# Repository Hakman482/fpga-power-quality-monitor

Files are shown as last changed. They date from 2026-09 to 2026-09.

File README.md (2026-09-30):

# FPGA-Based Single-Phase Power Quality Monitor

A complete hardware–FPGA–software prototype for real-time single-phase power-quality measurement, developed as an MSc Electronic & Electrical Engineering project.

The system combines a custom 4-layer sensing/conditioning PCB, dual 16-bit SAR ADC acquisition, a Nexys A7-100T FPGA processing pipeline, UART telemetry, and a Python desktop GUI. The implementation measures and visualises RMS voltage/current, frequency, active/apparent power, power factor, harmonic distortion, raw ADC samples, waveforms, and voltage-event conditions.

> **Safety:** the hardware includes circuitry intended to interface with hazardous AC voltages. The prototype is an academic/laboratory design, not a certified measurement instrument. Do not connect it to mains unless you are qualified to work on hazardous voltages and have independently verified isolation, protection, creepage/clearance, grounding, enclosure and test procedures.

## Project highlights

- Custom **4-layer PCB** for isolated voltage sensing and Hall-effect current sensing.
- Two synchronized **ADS8320 16-bit SAR ADC** channels.
- **Nexys A7-100T / Artix-7** FPGA (`xc7a100tcsg324-1`).
- **10 kS/s per channel** synchronized acquisition.
- FPGA implementations for cycle-synchronous RMS, frequency measurement, active/apparent power, power factor, adaptive harmonic analysis through the 25th harmonic, and THD calculation.
- Real-data mode selected in the supplied top-level design (`TEST_MODE => false`).
- **115200-baud UART** with separate metric and waveform/raw-ADC packet formats.
- Python/Tkinter GUI with live dashboard, waveforms, raw ADC view, spectrum, events, validation tools and CSV recording.
- Experimental validation using function-generator voltage tests and DC current calibration, with measurement-uncertainty analysis.

## System architecture

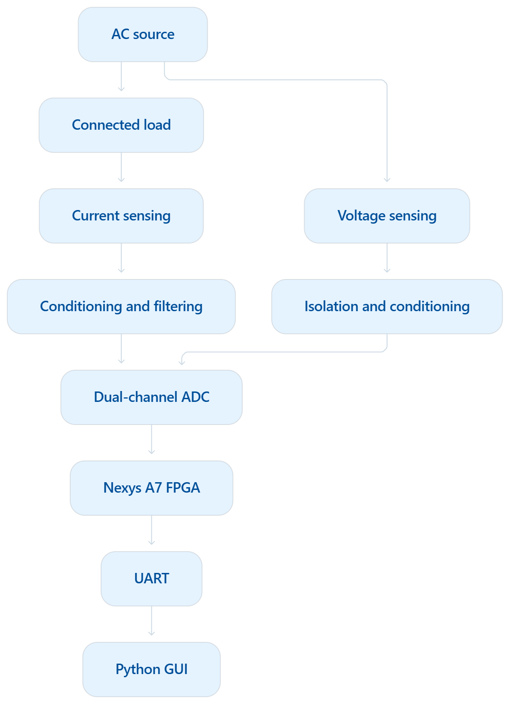
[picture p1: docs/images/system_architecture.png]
System architecture


`Voltage / Current sensing -> analogue conditioning -> dual ADC -> FPGA acquisition/DSP -> UART -> Python GUI`

### Measurement hardware

The voltage path uses an isolated-amplifier-based sensing chain followed by precision op-amp conditioning and anti-alias filtering before conversion by an ADS8320.

Current is sensed using an ACS724 Hall-effect sensor, conditioned around the analogue midpoint, filtered and digitised by the second ADS8320.

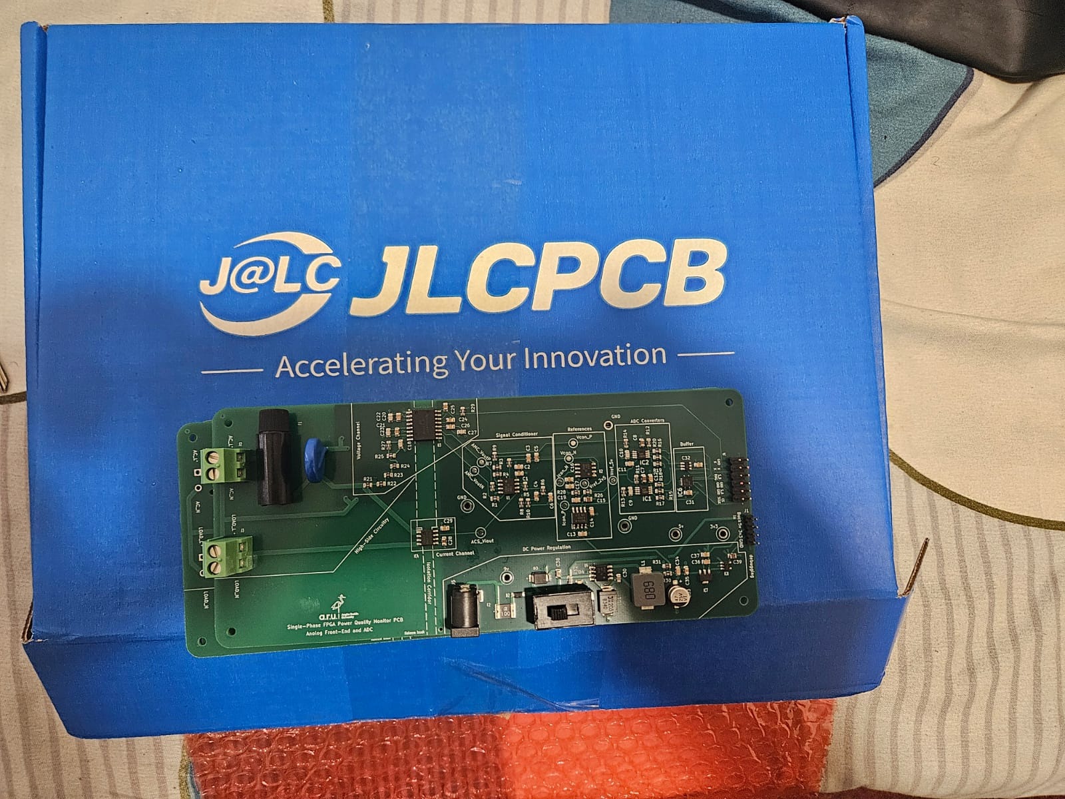
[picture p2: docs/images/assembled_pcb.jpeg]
Assembled PCB


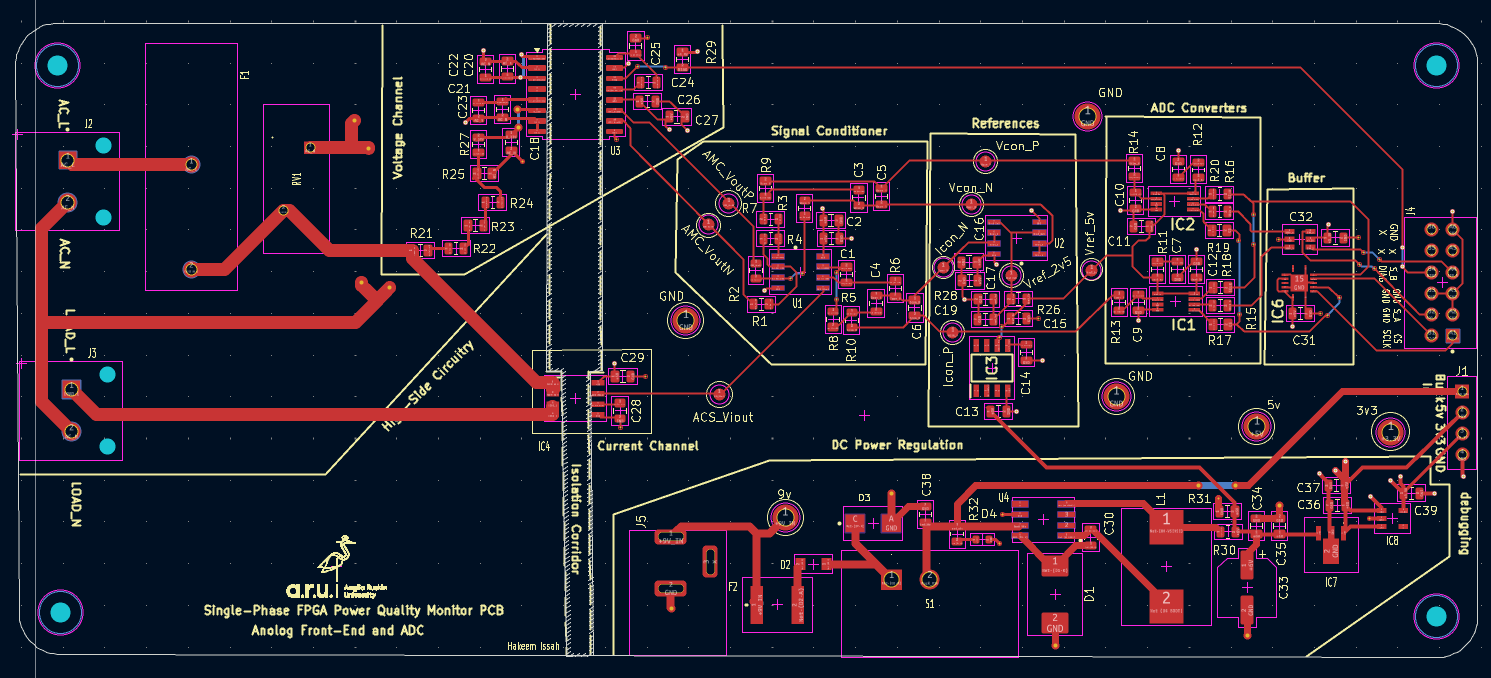
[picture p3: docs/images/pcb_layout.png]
PCB layout


## FPGA architecture

The final hardware design is in [`fpga/`](fpga/).

| Parameter | Value |
|---|---:|
| FPGA | Nexys A7-100T / `xc7a100tcsg324-1` |
| System clock | 100 MHz |
| ADC serial clock | 500 kHz |
| Sampling rate | 10 kS/s/channel |
| Nominal mains frequency | 50 Hz |
| Nominal RMS/power window | 200 samples |
| Maximum adaptive THD cycle frame | 210 samples |
| UART | 115200 baud, 8N1 |
| Waveform frame | 1000 sample pairs |
| Waveform capture interval | approximately 2 s |

See [`fpga/README.md`](fpga/README.md) for the module breakdown and Vivado build instructions.

## UART protocol and GUI

Two packet families are transmitted:

- `AA55`: FPGA-computed power-quality metrics.
- `AA56`: versioned V/I sample frames containing raw 16-bit ADC codes and scaled engineering-unit samples.

A 1000-pair frame represents 100 ms of data at 10 kS/s, or about five cycles of a 50 Hz waveform. Continuous raw streaming is deliberately avoided because 115200-baud UART cannot carry the full 10 kS/s sample stream continuously.

The Python GUI is in [`gui/`](gui/).

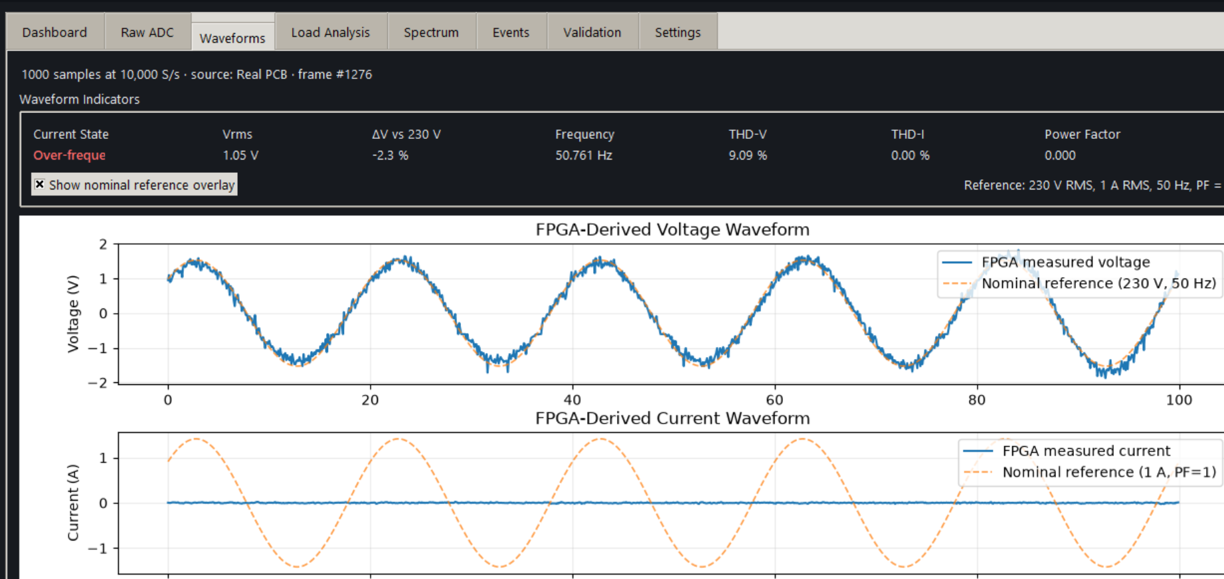
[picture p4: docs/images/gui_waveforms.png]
GUI waveform view


```bash
cd gui
python -m pip install -r requirements.txt
python main.py
```

## Validation

The project was validated using low-voltage sinusoidal input tests for the voltage chain and DC current calibration for the current chain. Oscilloscope/logic measurements were also used to verify conversion cadence, ADC serial-clock bursts and activity on both ADC data lines.

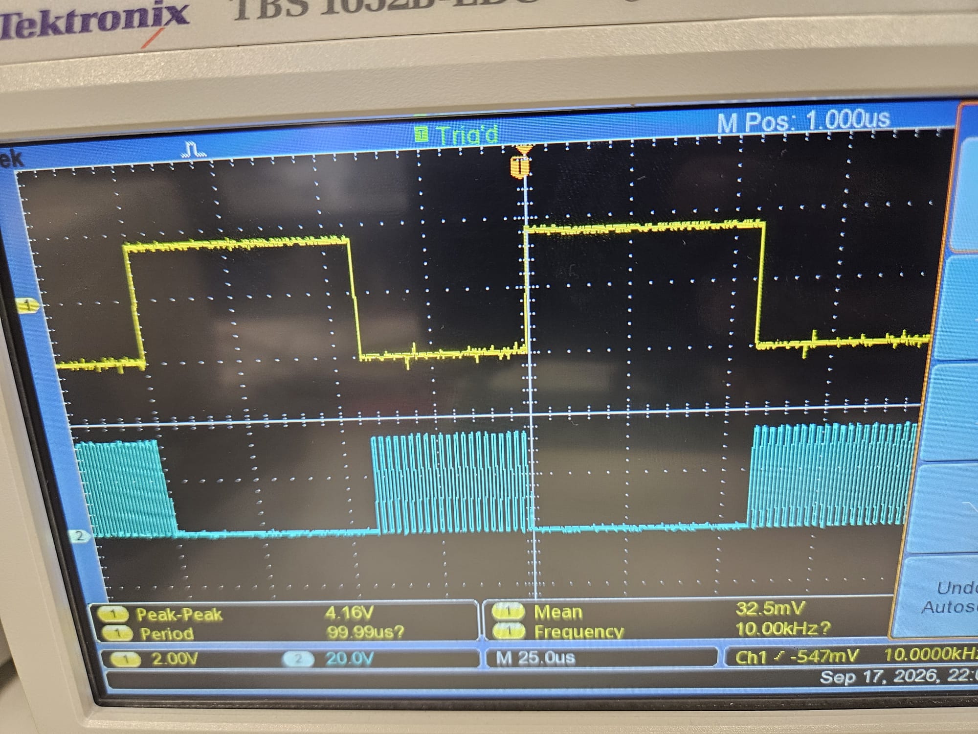
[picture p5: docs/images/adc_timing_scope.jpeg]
ADC timing verification


The original GUI CSV format is preserved. Most captures are stored directly as `.csv`. Four captures exceeded the transfer size used to populate this repository and are therefore stored **losslessly** as gzip-compressed CSV files:

- `validation/current/raw/raw_adc_0.05A.csv.gz`
- `validation/current/raw/raw_adc_0.2A.csv.gz`
- `validation/current/raw/raw_adc_0.25A.csv.gz`
- `validation/voltage/raw/raw_adc_cali_10pp.csv.gz`

They decompress to the original CSV bytes, e.g.:

```bash
gzip -dk validation/current/raw/raw_adc_0.25A.csv.gz
```

Known isolated acquisition glitches are preserved in the source captures. Analysis excludes isolated invalid codes such as exact `24576` and `49152` samples where they represent acquisition artefacts rather than real measurements. See [`validation/README.md`](validation/README.md).

## Hardware and manufacturing

Editable KiCad sources, the full custom footprint/symbol libraries, repository-relative 3D models, Gerbers, drill files, BOM and component-placement outputs are under [`hardware/`](hardware/).

The board source can be opened from:

```text
hardware/kicad/myProject.kicad_pro
```

## Repository layout

```text
.
├── README.md
├── .gitignore
├── CITATION.cff
├── fpga/
│   ├── src/             # final active VHDL
│   ├── sim/             # simulation/testbench sources
│   ├── legacy/          # earlier auto-disabled modules
│   ├── constraints/
│   └── scripts/
├── gui/                 # Python GUI and UART parser
├── hardware/
│   ├── kicad/
│   └── manufacturing/
├── validation/
│   ├── current/
│   ├── voltage/
│   └── analysis/
└── docs/
    ├── images/
    └── academic/
```

## Rebuilding the FPGA project

Generated Vivado cache/run files are intentionally omitted.

From Vivado Tcl:

```tcl
source fpga/scripts/create_project.tcl
```

The original project was developed with Vivado 2026.1. Re-run synthesis, implementation and timing checks in your installed Vivado release before programming hardware.

## Academic material

The project-defence presentation is included under `docs/academic/`.

The final dissertation itself is not duplicated in this Git repository; the repository is intended to expose the engineering implementation, design files, evidence and reproducible validation assets rather than act as a dissertation archive.

## Scope and limitations

This repository documents a working academic prototype rather than a certified power-quality analyser. Laboratory-source constraints limited voltage validation to low-voltage controlled inputs, and current calibration was performed at sub-ampere DC levels. Transient/event functionality was not developed into a full standards-compliant disturbance classifier.

## Author

**Hakeem Issah**  
MSc Electronic & Electrical Engineering project, 2026.

## Use and licensing

No open-source licence is asserted. The material is shared as academic/portfolio work. Contact the author before reusing substantial portions in another project or publication.

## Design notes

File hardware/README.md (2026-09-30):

# Hardware and PCB

Editable KiCad design files and manufacturing outputs for the custom measurement PCB.

## Design source

Open:

```text
kicad/myProject.kicad_pro
```

The project includes:

- top-level schematic and hierarchical sheets,
- 4-layer PCB layout,
- custom symbols,
- custom footprints,
- 3D component models.

The board implements the voltage/current sensing and conditioning chains, ADC interfaces, reference/power circuitry and FPGA interconnect used by the prototype.

## Manufacturing outputs

`manufacturing/` contains:

- Gerber files,
- plated/non-plated drill files,
- component-placement files,
- BOM,
- JLC assembly placement/CPL export.

These are retained separately from the editable KiCad design so it is clear which files are source and which are generated fabrication outputs.

## Safety and fabrication warning

This board was built and tested as an academic prototype. Manufacturing files are provided for project traceability, not as a statement that the design is certified or suitable for direct deployment on a mains installation.

Before reproducing or energising the board, independently review at least:

- insulation/isolation ratings,
- creepage and clearance,
- fuse/protection coordination,
- earthing and oscilloscope-grounding strategy,
- component voltage/current ratings,
- PCB material and manufacturing tolerances,
- enclosure and touch protection.

Do not infer regulatory compliance from the presence of Gerbers or a successful prototype build.

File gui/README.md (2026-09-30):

# Python GUI

Desktop interface for the FPGA power-quality monitor.

## Features

- FPGA metrics dashboard
- raw 16-bit voltage/current ADC display
- waveform plotting
- spectrum/harmonic view
- event/status table
- validation page
- serial-port settings
- raw CSV recording

No Python-generated measurement source is used in the final application. The selectable data modes refer to whether the FPGA itself is running its internal test source or the physical PCB input path.

## Requirements

```bash
python -m pip install -r requirements.txt
```

Dependencies:

- NumPy
- Matplotlib
- PySerial
- Tkinter (normally provided with desktop Python installations)

## Run

```bash
python main.py
```

Connect to the Nexys A7 USB-UART interface at **115200 baud**.

## Packet formats

### `AA55` metric packet

Carries the FPGA-computed measurement metrics.

### `AA56` waveform/raw packet, protocol version 2

Header and metadata are followed by V/I sample pairs.

Each sample pair contains:

- unsigned 16-bit voltage ADC code,
- unsigned 16-bit current ADC code,
- signed 32-bit voltage in millivolts,
- signed 32-bit current in microamps.

Multi-byte fields are MSB-first.

The final FPGA configuration captures 1000 sample pairs at 10 kS/s. This preserves the full 100 µs sample spacing within the 100 ms capture without attempting to stream every sample continuously over the 115200-baud serial link.

## CSV capture

Raw recording keeps both original ADC codes and scaled values. The data in `../validation/` was captured through this path.

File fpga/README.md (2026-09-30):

# FPGA implementation

This directory contains the final VHDL implementation for the Nexys A7-100T and the associated simulation sources.

## Active synthesis sources

| Module | Purpose |
|---|---|
| `pq_nexys_top.vhd` | Final top-level integration: acquisition, DSP, packet formatting and UART. |
| `acquisition_pipeline.vhd` | Selects internal-test or real-ADC acquisition and coordinates the measurement pipeline. |
| `adc_if.vhd` | ADS8320 serial-interface building block. |
| `dual_adc_if.vhd` | Simultaneously controls the two ADS8320 channels and returns synchronized 16-bit samples. |
| `sample_preprocess.vhd` | Removes measured channel zero offsets and produces signed, zero-centred ADC counts. |
| `sample_scale_v2.vhd` | Converts zero-centred counts to voltage/current engineering units using measured calibration factors. |
| `dual_rms.vhd` | Cycle-synchronous voltage/current RMS engine. |
| `frequency_meter.vhd` | Frequency measurement from the conditioned voltage waveform. |
| `power_meter_v2.vhd` | Cycle-synchronous active/apparent power and power-factor calculation. |
| `sample_frame_buffer.vhd` | Stores one adaptive electrical cycle for harmonic processing. |
| `harmonic_1_25_extractor.vhd` | Fixed-point Goertzel harmonic engine for the fundamental and harmonics 2–25. |
| `thd_1_25_meter.vhd` | Converts harmonic energy terms into V/I THD results. |
| `test_signal_source.vhd` | Internal deterministic waveform source for FPGA-only validation. |
| `pq_uart_packet_tx.vhd` | Formats metric packets plus raw/scaled V/I sample frames. |
| `uart_tx.vhd` | 115200-baud byte transmitter. |

Earlier modules that were auto-disabled in the submitted Vivado project are retained in `legacy/` for traceability but are not added by the clean build script.

## Final configuration

The supplied `pq_nexys_top.vhd` uses:

```vhdl
TEST_MODE => false
```

so normal synthesis targets the physical PCB/ADS8320 acquisition path.

Important values in the final top level:

```text
SYS_CLK_HZ            = 100,000,000
ADC_DCLOCK_HZ         = 500,000
SAMPLE_RATE_HZ        = 10,000
RMS_WINDOW_SAMPLES    = 200
POWER_WINDOW_SAMPLES  = 200
THD_FRAME_SAMPLES     = 210
SAMPLE_FRAME_SAMPLES  = 1,000
FRAME_PERIOD_SAMPLES  = 20,000
UART_BAUD              = 115,200
```

## Pin mapping

The included XDC targets the Nexys A7-100T:

| Function | Board pin |
|---|---|
| 100 MHz clock | E3 |
| Reset / BTNC | N17 |
| ADC chip select / JA1 | C17 |
| ADC serial clock / JA2 | D18 |
| Voltage ADC data / JA3 | E18 |
| Current ADC data / JA4 | G17 |
| USB-UART TX | D4 |

## Clean Vivado project

Generated Vivado output is deliberately not stored in the repository.

Run the project-generation Tcl script from the repository root:

```tcl
source fpga/scripts/create_project.tcl
```

Then run Synthesis, Implementation and Generate Bitstream.

Target device:

```text
xc7a100tcsg324-1
```

The original project file was created with Vivado 2026.1.

## Simulation

The `sim/` directory contains focused testbenches for the acquisition interface, RMS, frequency, harmonic/THD pipeline, power meter, UART packets and the integrated PQ pipeline.

Some testbenches exercise legacy variants as part of the development record; use the final `*_1_25_*`, `power_meter_v2` and `pq_uart_packet_tx` paths for the final architecture.

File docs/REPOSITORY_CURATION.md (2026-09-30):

# Repository curation notes

The original working archive contained 884 items, including source files, generated build artefacts, backups, research literature, component datasheets, repeated photographs and laboratory captures.

This GitHub package intentionally keeps the engineering outputs that are useful for review and reproduction while excluding unrelated or redundant material.

## Included

- final active VHDL implementation;
- VHDL simulation/testbench sources;
- earlier auto-disabled VHDL modules under `fpga/legacy/`;
- final Nexys A7 constraints;
- Python GUI and UART protocol code;
- editable KiCad schematic/PCB files;
- custom KiCad symbols, footprints and 3D models;
- Gerber/drill/BOM/placement manufacturing outputs;
- raw voltage/current validation CSV files;
- final dissertation and defence presentation;
- selected photographs/screenshots that document the system.

## Excluded

- Vivado cache, synthesis/implementation run folders, checkpoints, logs and generated bitstream;
- KiCad automatic backups;
- duplicate/near-duplicate photographs;
- exploratory screenshots that do not add useful documentation;
- downloaded research papers;
- vendor datasheets;
- temporary notes and miscellaneous debugging artefacts.

Research papers and vendor datasheets are deliberately not republished here because they are third-party material and are not required to understand the implementation.

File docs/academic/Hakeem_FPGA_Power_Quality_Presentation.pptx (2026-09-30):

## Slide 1

ENGINEERING MAJOR PROJECT

FPGA-Based Power Quality
Monitoring

with Measurement Uncertainty Analysis

Hakeem Issah (2452525)

MSc Electronic/Electrical Engineering
Anglia Ruskin University · September 2026
Supervisor: Dr. Sufian Yousef

Custom 4-layer sensing PCB + Nexys A7 FPGA + Python GUI

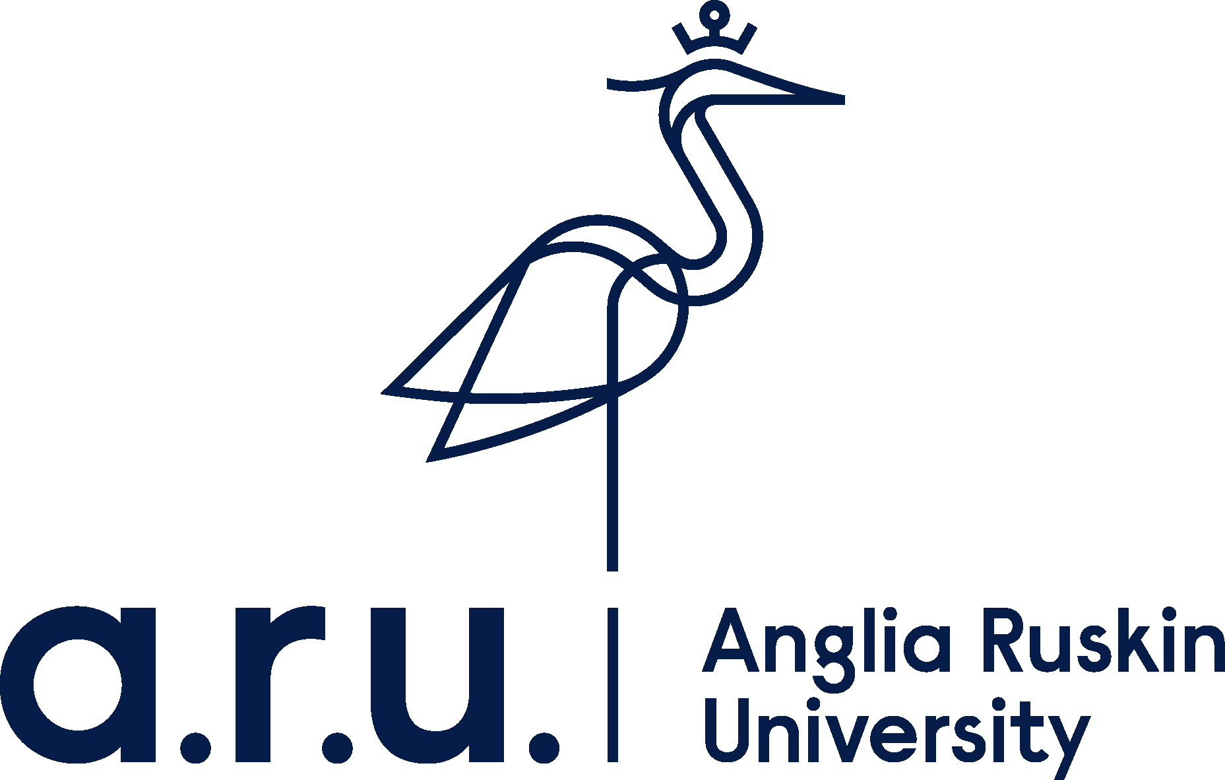
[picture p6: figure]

10-minute presentation

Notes: Good morning. My project is an FPGA-based single-phase power quality monitoring system with a particular focus on measurement uncertainty. The system combines a custom analogue sensing PCB, two 16-bit ADS8320 ADCs, a Nexys A7 FPGA and a Python GUI. Rather than only showing that the algorithms work, I also evaluated how well the complete measurement chain represents the applied input and where the available reference instruments limit the conclusions.

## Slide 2

MOTIVATION

Problem and project aim

The engineering problem

Correct FPGA maths does not guarantee correct measurement.
Sensor offset, analogue gain, noise, ADC reference and channel timing can all alter the samples before processing.

A prototype must therefore be tested as a complete measurement chain.

Sensing

Conditioning

16-bit ADC

FPGA

GUI

measurement uncertainty enters before the digital result

Design and implement a single-phase FPGA-based power quality monitor, then evaluate its measurement-chain performance using calibration, reference comparisons and uncertainty analysis.

Project aim

50 Hz nominal

10 kS/s / ch

Single phase

16-bit ADC

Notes: The central problem is that an FPGA can calculate RMS or THD correctly and the displayed answer can still be inaccurate because the samples may already contain gain error, offset, noise or timing error. That is why my aim was not only to build the monitor, but to evaluate the measurement chain itself. The design targets a 50 hertz single-phase system, samples both channels at 10 kilosamples per second, and uses 16-bit ADCs.

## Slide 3

LITERATURE REVIEW

Selected literature and research gap

Study | Relevant evidence | Limit on transfer
Yildirim et al. (2018) | FPGA-based online power-quality monitoring using continuously acquired voltage and current signals. | Different sensing hardware, network conditions and communication architecture.
De Oro Arenas et al. (2021) | FPGA smart-energy meter with analogue acquisition, power-quantity calculation, Goertzel harmonics and calibration. | Three-phase system with different sensors and ADC arrangement.
Maśnicki et al. (2025) | Review stressing modelling, development and validation of the complete measuring channel for power-quality assessment. | General measuring-channel framework; not the exact AMC3330 / ACS724 / ADS8320 chain.

Research gap addressed: complete measurement-chain validation and uncertainty, not only FPGA algorithm demonstration.

FPGA-Based Power Quality Monitoring Hakeem Issah · MSc Electronic/Electrical Engineering · 3

Adapted from dissertation Table 2.1

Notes: This literature-review slide is a short version of the table in Chapter 2. I would explain that previous work supports FPGA use for deterministic and parallel power-quality processing. Yildirim et al. show online FPGA monitoring, and De Oro Arenas et al. show an FPGA smart-energy meter with Goertzel harmonics and calibration. Maśnicki et al. is important because it stresses that the whole measuring channel must be validated. My gap is therefore not simply implementing another algorithm. It is integrating the sensing PCB, ADCs, FPGA and GUI, then checking what the measurements and uncertainty actually support.

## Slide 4

WHAT I BUILT

System architecture

Separate physical test sources feed a common hardware–FPGA–GUI chain.

Signal generator

voltage test

Voltage sensing

divider + AMC3330

Conditioning

OPA2188 + filter

ADS8320 V

16-bit SAR

Nexys A7

PQ processing

Python GUI

UART 115200

DC supply + load

current test

Current sensing

ACS724 Hall sensor

Conditioning

OPA2188 + filter

ADS8320 I

16-bit SAR

AMC3330

voltage isolation

ACS724

current sensor

2 × ADS8320

conversion

10 kS/s / ch

sampling

Goertzel 1–25

harmonics

Shared ADC control gives a common sampling schedule; exact analogue phase alignment was not physically established.

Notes: This is the overall architecture. The voltage path uses a divider, AMC3330 isolation and OPA2188 conditioning before a dedicated ADS8320. The current path uses an ACS724 Hall sensor, OPA2188 conditioning and a second ADS8320. Both converters are controlled by the Nexys A7 at 10 kilosamples per second. The FPGA calculates the power-quality quantities and sends results to a Python GUI over UART. The two ADCs share control timing, but because the analogue paths are different, that does not by itself prove exact phase alignment.

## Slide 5

PHYSICAL IMPLEMENTATION

Hardware prototype and commissioning

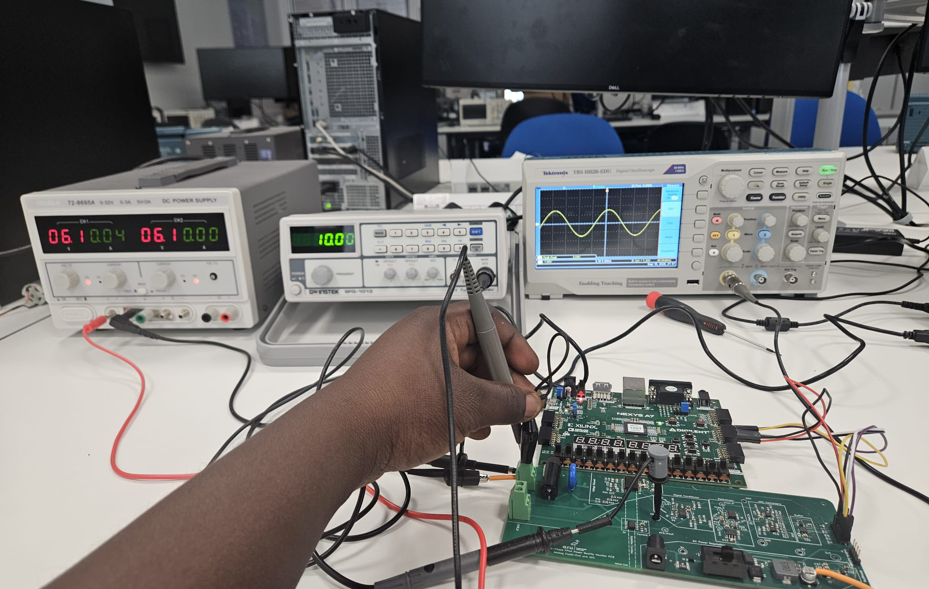
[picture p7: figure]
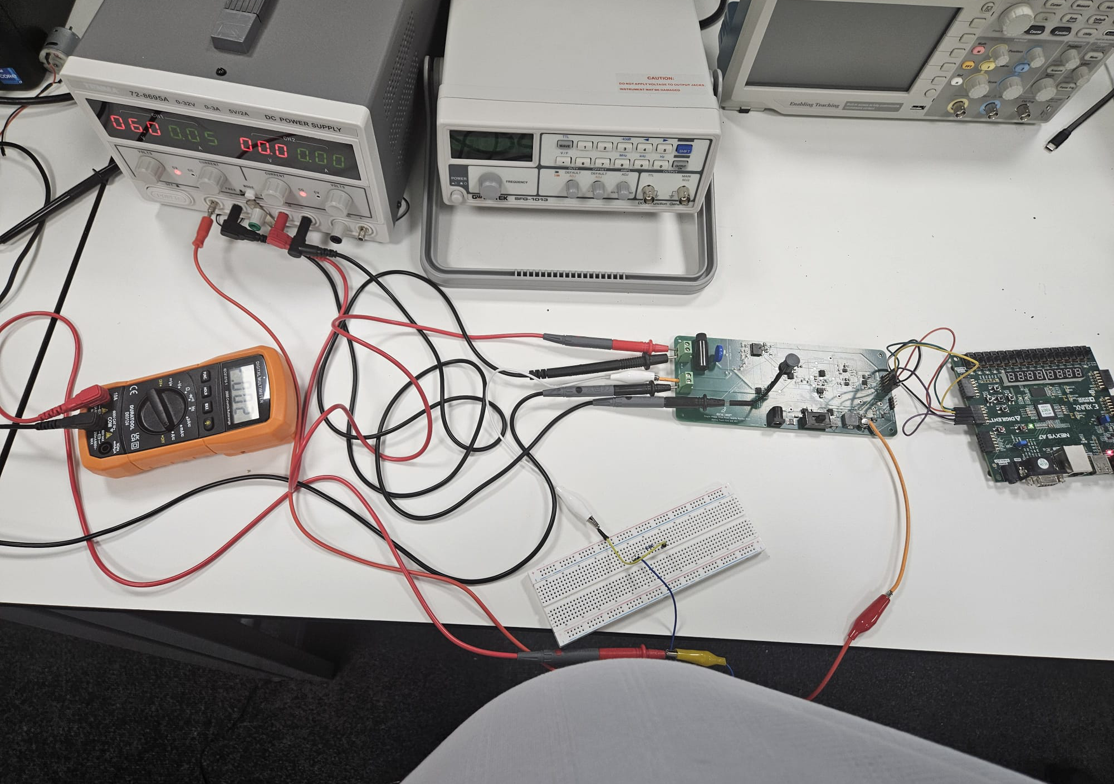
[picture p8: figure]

As-built revisions

• External 6 V applied at C33
• Original 9 V path disconnected
• AMC3330 LDO_OUT–DCDC_IN jumper
• Results refer to this modified configuration

4-layer custom PCB

REF5050 5 V reference

Vcon_P / Vcon_N

Icon_P / Icon_N

Left: voltage-channel lab setup. Top-right: final PCB layout. Bottom-right: DC current test setup.

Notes: The hardware was implemented on a custom four-layer PCB. The board includes isolation and conditioning for voltage, Hall-effect current sensing, a precision five-volt reference and two ADCs. Commissioning also revealed real prototype issues. The original buck-supply section was bypassed, so the final tests used an external six-volt supply at C33, and the AMC3330 required a jumper between LDO_OUT and DCDC_IN. I report those changes explicitly because the results apply to the actual as-tested hardware, not only to the original schematic.

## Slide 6

DIGITAL IMPLEMENTATION

FPGA processing and software interface

ADC pair
16-bit

Offset removal
+ scaling

Parallel
processing

AA55 / AA56
packetisation

UART
115200

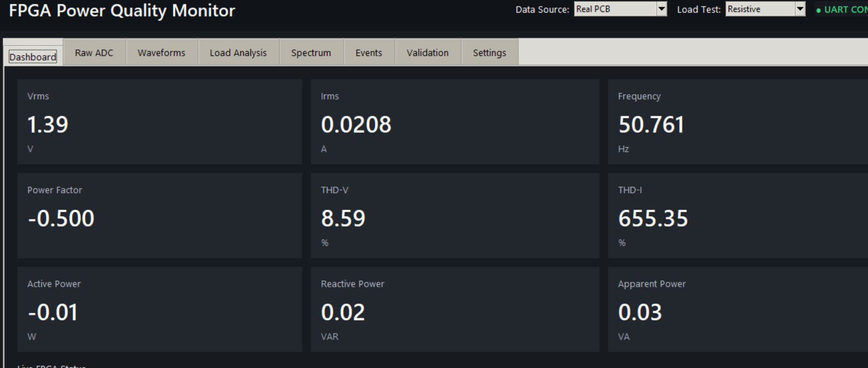
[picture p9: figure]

RMS | frequency | active / apparent power | PF | sag/swell | adaptive Goertzel THD

• TEST_MODE = false for final physical tests
• 1000-sample waveform frames = 0.1 s of data
• Frequency-adaptive Goertzel targets harmonics 1–25
• Fixed-width / integer arithmetic to control FPGA cost
• Raw ADC data can be exported to CSV

Implementation choices

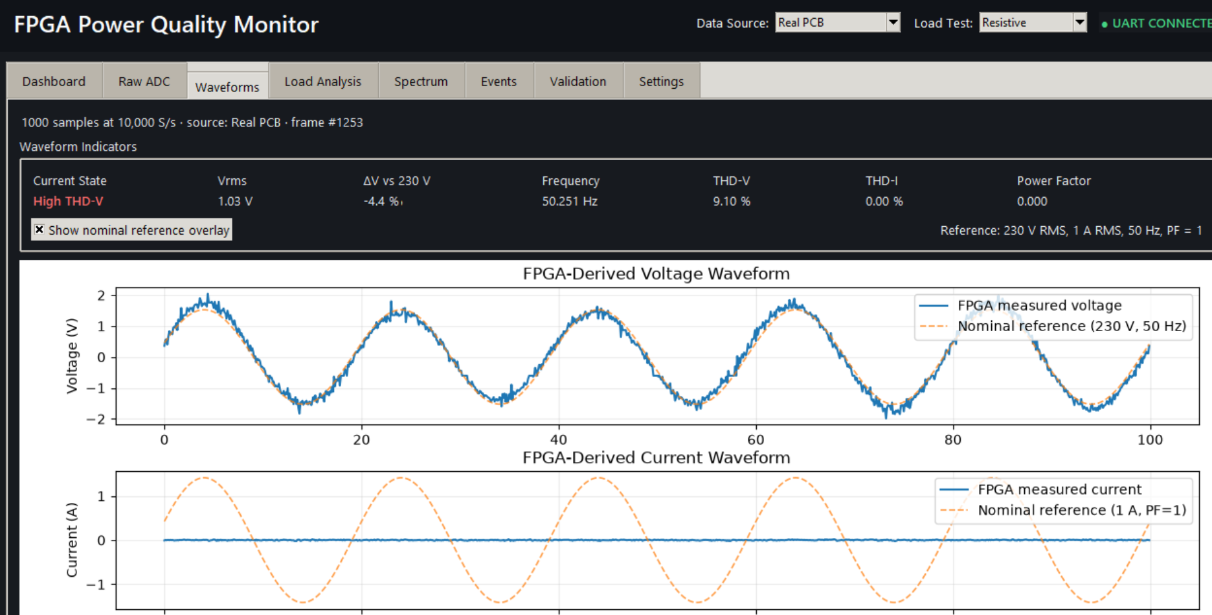
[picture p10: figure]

100 MHz

FPGA clock

100 µs

sample period

1000 samples

frame size

AA56 v2

packet build

115200 baud

host link

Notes: Inside the FPGA, each 16-bit ADC sample is offset-corrected, scaled and fed to several processing blocks in parallel. The implemented functions include RMS, frequency, power, power factor, sag and swell detection, and adaptive Goertzel harmonic processing up to the twenty-fifth harmonic. The final physical tests used TEST_MODE false, so the system processed real ADC samples. Scalar metrics and waveform data are packetised separately and sent to the Python GUI, which also records raw ADC data for offline analysis.

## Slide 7

HOW I TESTED IT

Experimental method

• RMS validation at 3 low-voltage levels
• Frequency operation
• Physical sag/swell detection
• THD behaviour, but no matched independent THD reference

Voltage channel

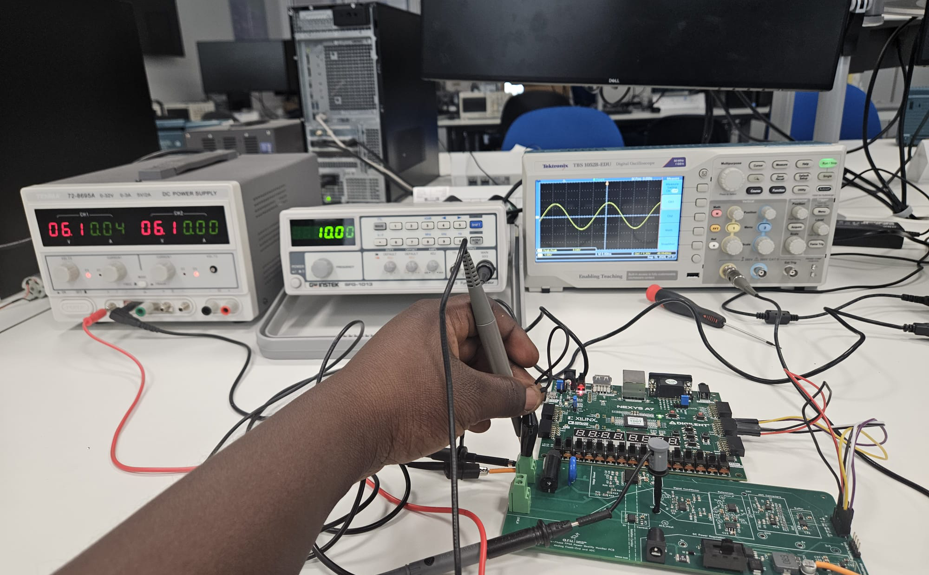
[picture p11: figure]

What it supports

• Zero-input offset and static sensitivity
• DC calibration over 0–0.46 A
• Linearity and repeatability
• Not AC current, phase or harmonic validation

Current channel

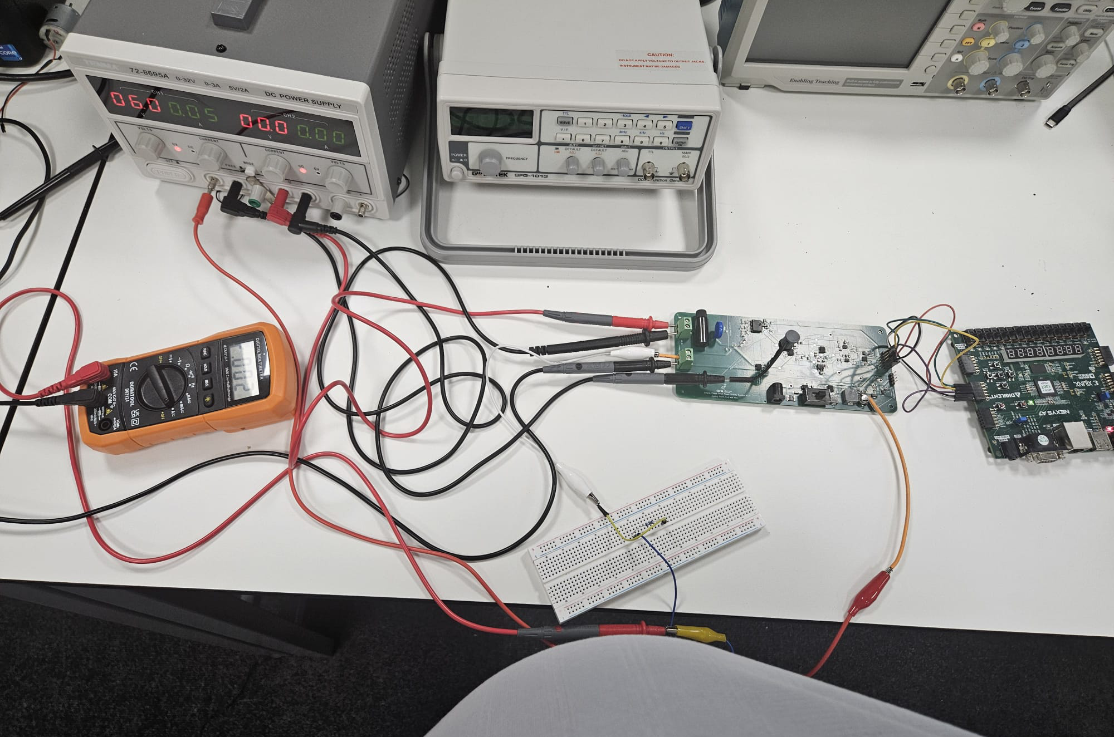
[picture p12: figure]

What it supports

Input / reference

Signal generator + Tektronix TBS1052B-EDU with P2200 probe at 10×

Input / reference

DC bench supply + resistive load + Duratool D03124 multimeter on 10 A range

Important scope decision: the channels were tested separately because no suitable isolated variable AC source was available. These were not simultaneous AC-load measurements.

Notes: Because there was no suitable isolated variable AC source, I deliberately used two separate experiments. For voltage, I used a signal generator and measured the actual test-point amplitude with a Tektronix TBS1052B-EDU and P2200 probe at ten-times attenuation. This supports low-voltage RMS comparisons, frequency operation and physical sag and swell tests. For current, I used a DC supply, resistor and Duratool D03124 on its ten-amp range, covering zero to about 0.46 amps. That supports static calibration and linearity, but not AC phase, current harmonics or live-load power-factor accuracy.

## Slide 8

WHAT THE DATA SHOWED

Key results

Three-point fit: R² = 0.994 · MAPE = 2.63%

Voltage RMS validation

DC current-channel validation

Observed comparison differences were small, but the reference DMM was too coarse for mA-level accuracy claims.

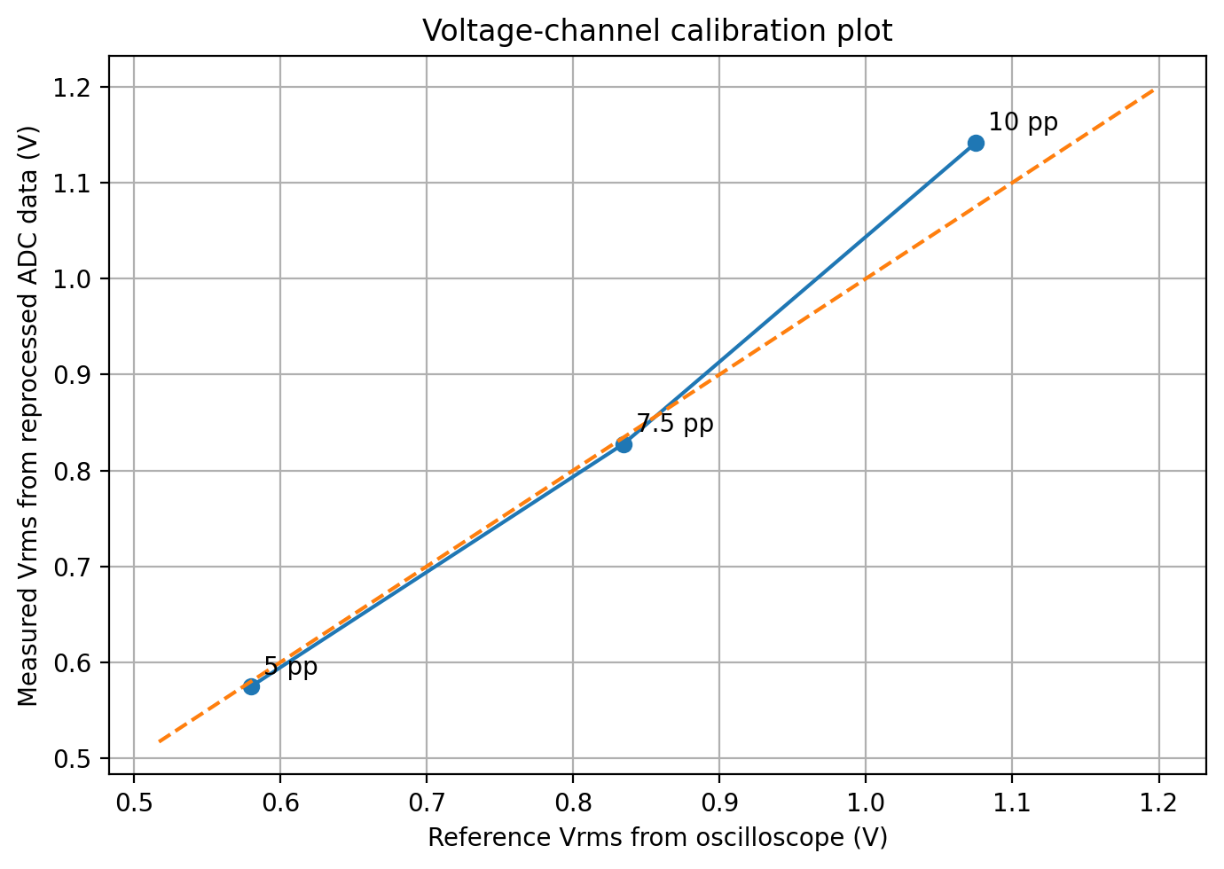
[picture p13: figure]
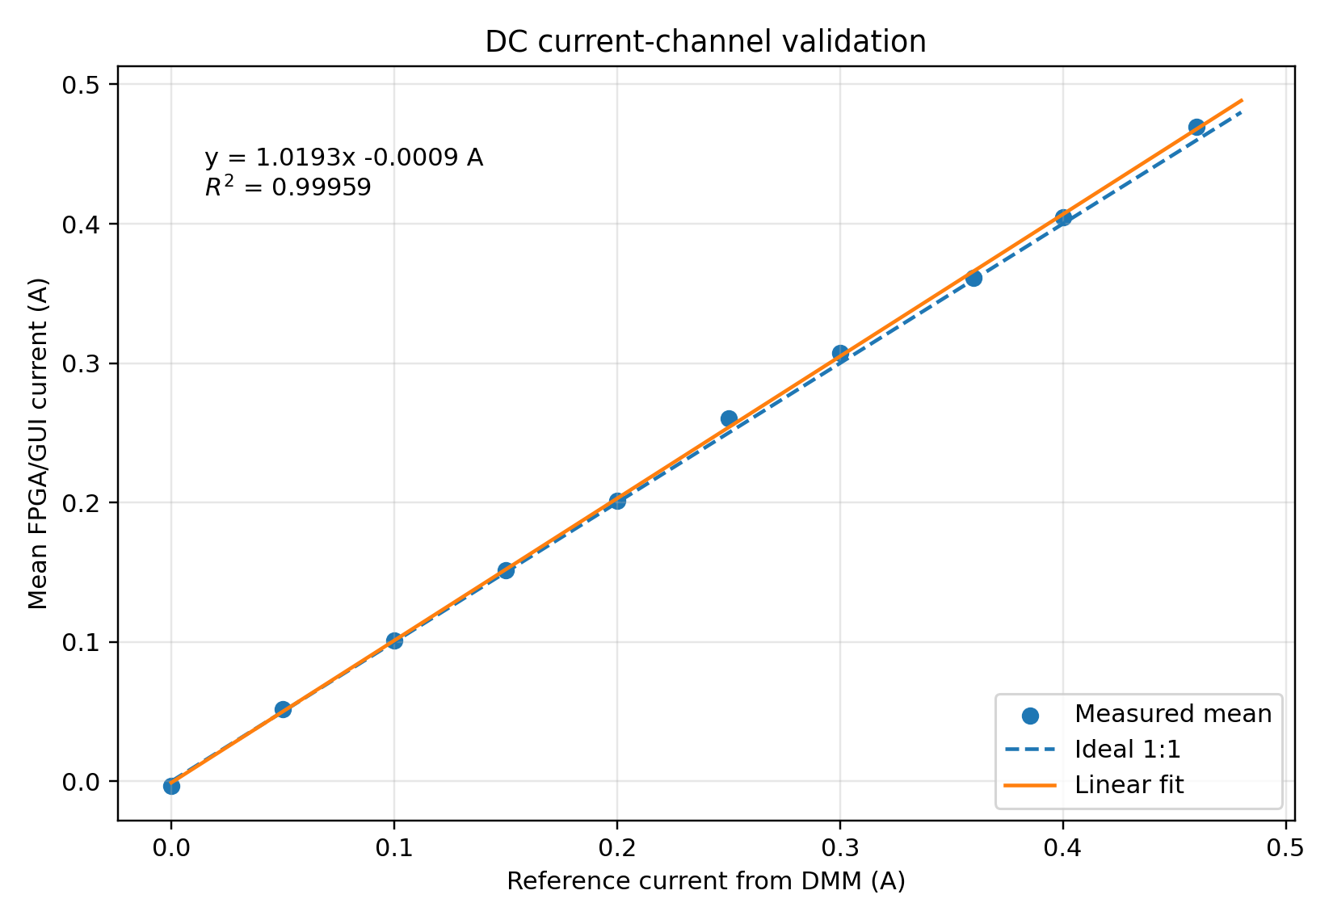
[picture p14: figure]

−0.90%

5 Vpp nominal

−0.81%

7.5 Vpp nominal

+6.18%

10 Vpp nominal

0–0.46 A

tested range

R² 0.99959

linearity

1.0193×

gain fit

CS = 10.00 kHz

physical sample cadence

WNS +0.327 ns

timing closure

LUT 10.43%

resource use

DSP 25.0%

resource use

Sag/swell functional

events

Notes: These are the key quantitative results. For voltage RMS, the first two test levels agreed with the oscilloscope to within about one percent, while the highest level showed a positive error of 6.18 percent. The three-point response was still strongly linear, with an R-squared of 0.994. For the current channel, the response from zero to 0.46 amps was extremely linear, with R-squared approximately 0.9996. On the FPGA side, the measured conversion cadence was 10 kilohertz, the final build met timing with positive worst setup slack, and resource utilisation remained modest. Physical sag and swell changes were also detected successfully.

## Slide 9

WHAT CAN BE CLAIMED

Voltage uncertainty and limitations

Voltage RMS error vs U(k=2)

U(k=2): ±37.2 mV · ±41.5 mV · ±56.7 mV

Voltage RMS uncertainty contributors

Main contributors: scope gain, probe attenuation, repeatability and zero shift.

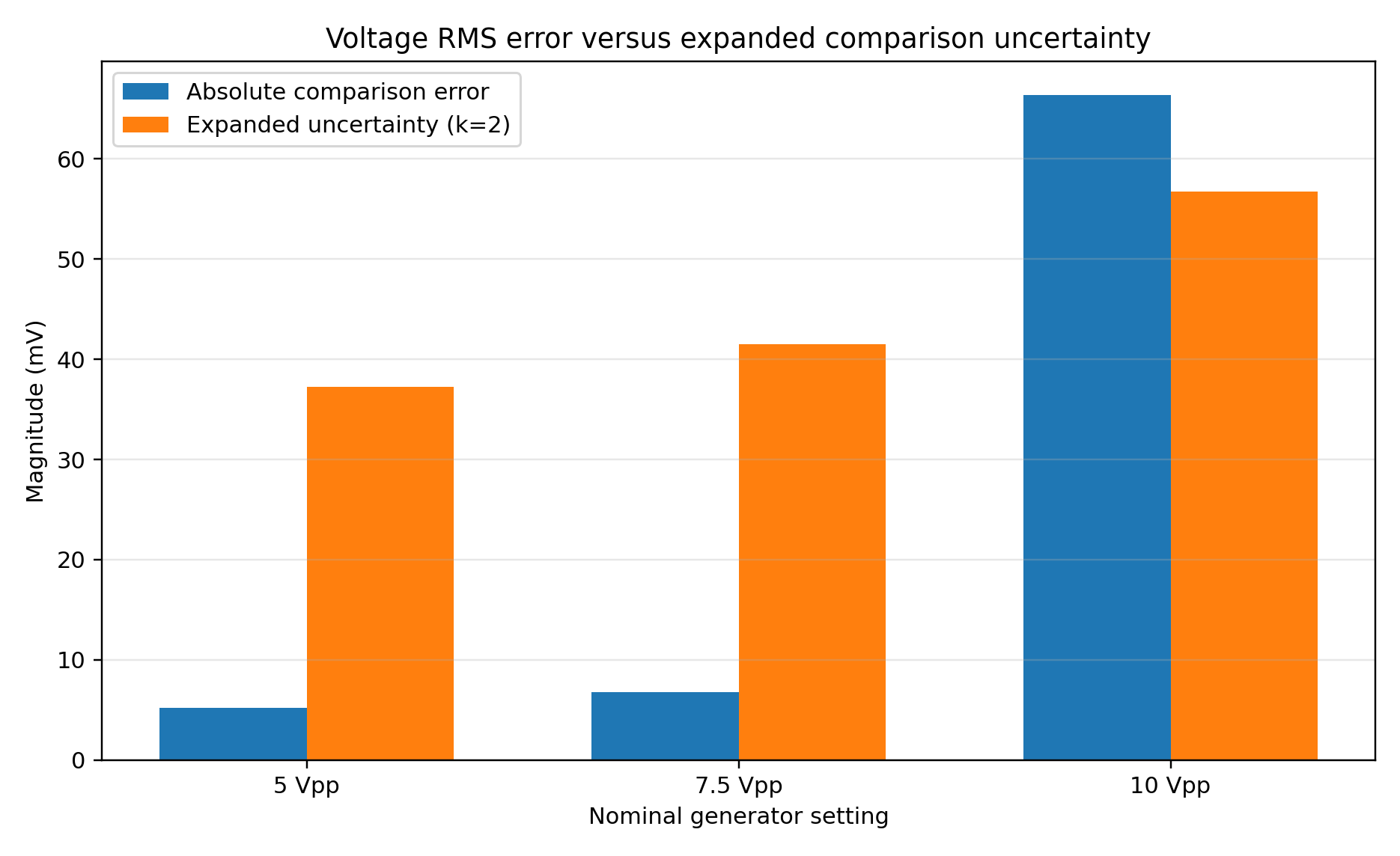
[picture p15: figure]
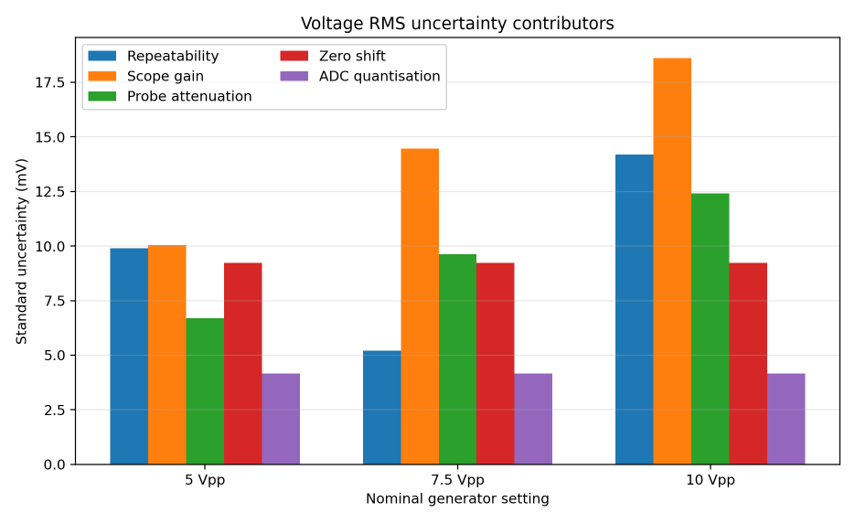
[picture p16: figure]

The 5 Vpp and 7.5 Vpp RMS errors are inside the estimated k=2 comparison intervals.
The 10 Vpp residual is still outside the interval, so an additional systematic effect or missing term is likely.
Therefore, the voltage channel is functional and roughly linear, but not justified as uniformly accurate across the range.

Interpretation

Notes: This slide explains how the results should be interpreted. For voltage, the expanded comparison uncertainties were about plus or minus 37, 42 and 57 millivolts. The first two errors fall inside those intervals, but the 10 Vpp residual of about 66 millivolts remains outside, suggesting an additional systematic effect or a missing uncertainty contribution. For current, the DMM ten-amp range dominates the uncertainty, so the experiment demonstrates linear response but not milliampere-level absolute accuracy. The key point is that the prototype works, but the evidence does not justify unsupported claims about simultaneous AC power, power factor or independently validated THD accuracy.

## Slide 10

WHAT CAN BE CLAIMED

Current uncertainty and limitations

Current uncertainty at 0.30 A

DMM Type-B term ≈ 32.3 mA standard uncertainty

The current channel response is highly linear over 0–0.46 A: R² ≈ 0.9996.
However, the Duratool D03124 was used on its 10 A range, so the reference uncertainty dominates.
Frame repeatability and ADC quantisation are very small compared with the DMM term.
The test supports DC calibration and response shape, but not milliampere-level absolute accuracy.

Need a calibrated low-current reference before high-accuracy claims.

Interpretation

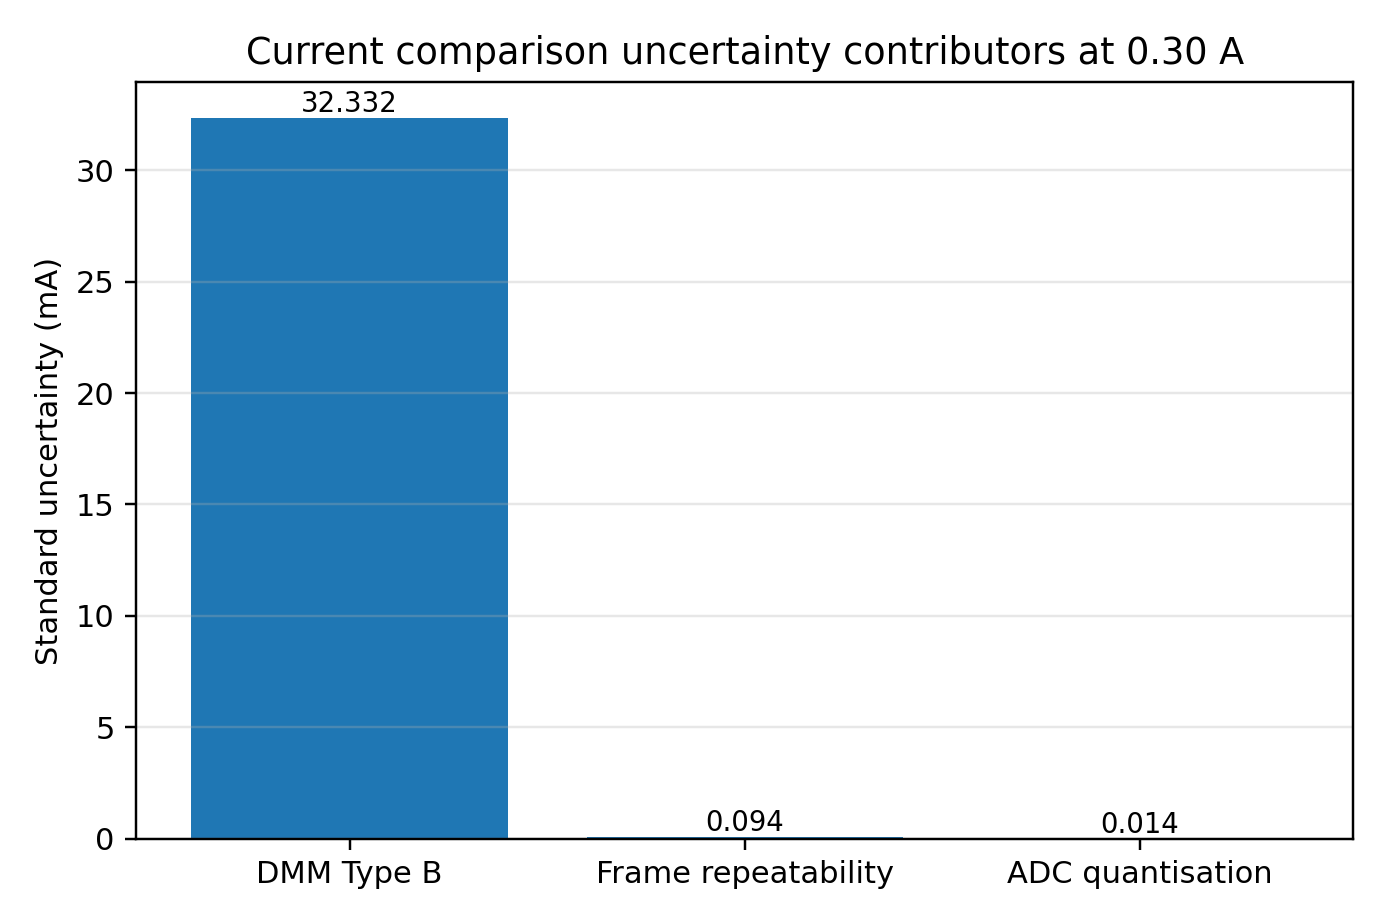
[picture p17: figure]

Main limit

Boundary: DC current calibration was completed; AC current, phase, power and power-factor accuracy were not physically validated.

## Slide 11

Conclusion and future work

Overall: the prototype is a functioning platform; the strongest future step is improved metrology, then full AC validation.

TAKEAWAY

Working FPGA power-quality prototype achieved.

Integrated platform

Custom sensing PCB, two ADS8320 ADCs, Nexys A7 FPGA, UART and Python GUI.

Validated evidence

Voltage RMS at three levels, DC current calibration, physical sag/swell and FPGA timing/resource results.

Key judgement

Functionality was claimed only where real test evidence and uncertainty support it.

Final result

Improve reference instruments

Use calibrated voltage and lower-current references.

Investigate 10 Vpp residual

Repeat with a documented reference chain and additional amplitude points.

Complete AC validation

Use an isolated AC source for phase, power and power-factor testing.

Validate THD independently

Apply known harmonic content and compare with a calibrated reference.

Revise hardware

Correct the power section and integrate the AMC3330 link on PCB.

Next steps

1

2

3

4

5

FPGA-Based Power Quality Monitoring

Hakeem Issah · MSc Electronic/Electrical Engineering

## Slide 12

THANK YOU

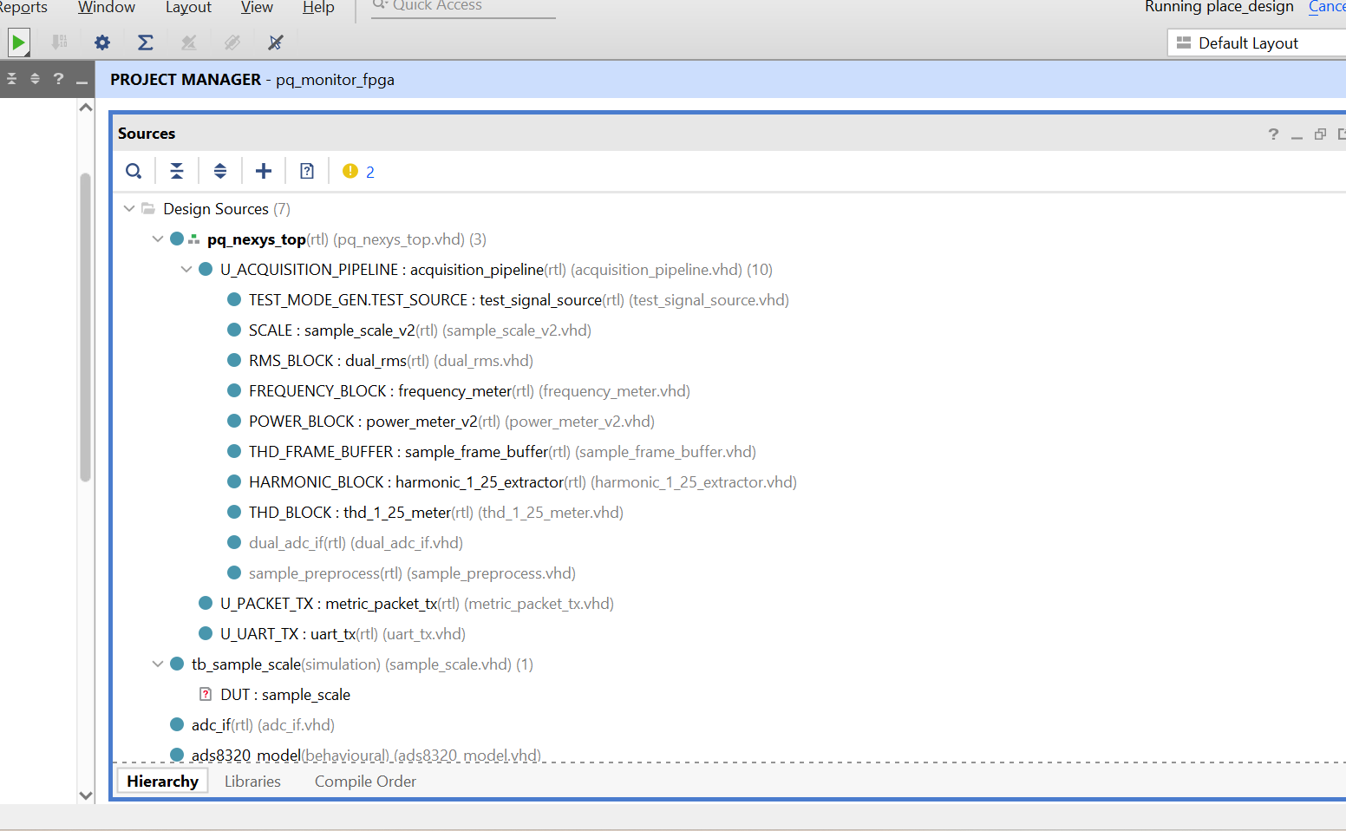
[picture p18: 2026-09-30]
docs/images/vivado_project.png

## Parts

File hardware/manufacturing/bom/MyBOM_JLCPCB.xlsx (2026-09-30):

Comment | Designator | Footprint | JLCPCB Part #（optional）
744770168 | L1 | Inductor_new_YJYCOIN_YSPI1040T_custom | C49140886
XDJK-0051-025_barrel | J5 | DC-470-2.1GP_C194407_barrel_custom | C7498153
ADS8320EB_2K5 | IC1,IC2 | SOP65P490X110-8N_ADC_custom | C22247
SN74LVC2G17DBVR | IC5 | SOT95P280X145-6N_buffer_a_b_custom | C10429
AP7375-33W5-7 | IC8 | SOT95P285X140-5N_ldo3.3v_custom | C2877825
OPA2188AID | U2,U1 | SOIC127P599X175-8Nopamp | C17271
1n | C23,C27,C22,C18,C10,C9 | C_0805_2012Metric | C701302
1730395(load) | J3 | PHOENIX_1730395_ac_load_con | C89120
10k | R1,R30,R28,R26,R4,R3,R2 | R_0805_2012Metric | C84376
TPS5410DR | U4 | SOIC127P599X175-8Nbuck | C28867
AMC3330 | U3 | SOIC-16W_7.5x10.3mm_P1.27mm_custom | C2999368
GND | TP15,GND,GND | TestPoint_Plated_Hole_D2.0mm
Vref_2v5 | Vref_2v5 | TestPoint_Pad_D1.5mm
Vref_5v | Vref_5v | TestPoint_Pad_D1.5mm
Icon_N | Icon_N | TestPoint_Pad_D1.5mm
Icon_P | Icon_P | TestPoint_Pad_D1.5mm
Vcon_N | Vcon_N | TestPoint_Pad_D1.5mm
Vcon_P | Vcon_P | TestPoint_Pad_D1.5mm
ACS_Viout | ACS_Viout | TestPoint_Pad_D1.5mm
AMC_VoutN | AMC_VoutN | TestPoint_Pad_D1.5mm
AMC_VoutP | AMC_VoutP | TestPoint_Pad_D1.5mm
+3.3V | 3v3 | TestPoint_Plated_Hole_D2.0mm
+5V | GND | TestPoint_Plated_Hole_D2.0mm
+9V_IN | 9v | TestPoint_Plated_Hole_D2.0mm
L101011MS02Q | S1 | L101011MS02Q_pswitch | C221823
B72214P2271K101 | RV1 | B72214P2271K101MOVV
2k2 | R32 | R_0805_2012Metric | C114561
2k55 | R31 | R_0805_2012Metric | C2681631
47k | R29 | R_0805_2012Metric | C126351
1k | R27,R10,R9,R8,R7 | R_0805_2012Metric | C95781
4k99 | R25 | R_0805_2012Metric | C114542
499k | R24,R23,R22,R21 | R_0805_2012Metric
47 | R20,R19,R18,R17,R16,R15 | R_0805_2012Metric | C114541
100 | R14,R13 | R_0805_2012Metric | C105577
0.22 | R12,R11 | R_0805_2012Metric | C327215
10K | R6 | R_0805_2012Metric | C84376
30K | R5 | R_0805_2012Metric | C126352
69168-112HLF | J4 | AMPHENOL_69168-112HLF_Odd_Even | C225521
1730395(ac_input) | J2 | PHOENIX_1730395_ac_load_con | C89120
Conn_01x04(debugging) | J1 | PinHeader_1x04_P2.54mm_Vertical | C492403
AP7375-50Y-13 | IC7 | AZ7042RTRG1_ldo5v | C22364247
SN74AHCT125RGYR | IC6 | RGY-_S-PVQFN-N14_cs_clk | C2675532
ACS724LLCTR-05AB-T | IC4 | SOIC127P600X175-8N_acs | C459328
REF5050AIDR | IC3 | SOIC127P600X175-8N_REF | C27804
SMD100F-2018-2 | F2 | SMD030F20182_polyfuse | C70149
4525holder & 0215001 fuse_catridge(installed) | F1 | FUSE_4525holder | C3205505
SGT520-1A T1AL250V 5x20mm Fuse | F1-FUSE | 5x20mm Fuse Cartridge (manual insert) | C41367255
SML-D12FWT86 | D4 | LED_0603_1608Metric | C22371379
SMBJ12A | D3 | DIOM4336X265N_tvs | C151251
SS34FA | D2 | SODFL3618X143Nschottky | C719833
B340 | D1 | D_SMC | C85099
10u | C39,C15,C8,C7 | C_0805_2012Metric | C126584
4.7uF | C38 | C_0805_2012Metric | C86040
100n | C37,C35,C32,C31,C29,C25,C24,C21,C16,C1 | C_0805_2012Metric | C83055
1u | C36,C34,C26,C20,C19,C14,C12,C11 | C_0805_2012Metric | C376925
47u | C33 | CP_Elec_6.3x5.8 | C970677
10n | C30 | C_0805_2012Metric | C342877
4n7 | C28 | C_0805_2012Metric | C415370
4u7 | C13,C2,C17 | C_0805_2012Metric | C86040
33n | C6,C5,C4,C3 | C_0805_2012Metric | C5375930

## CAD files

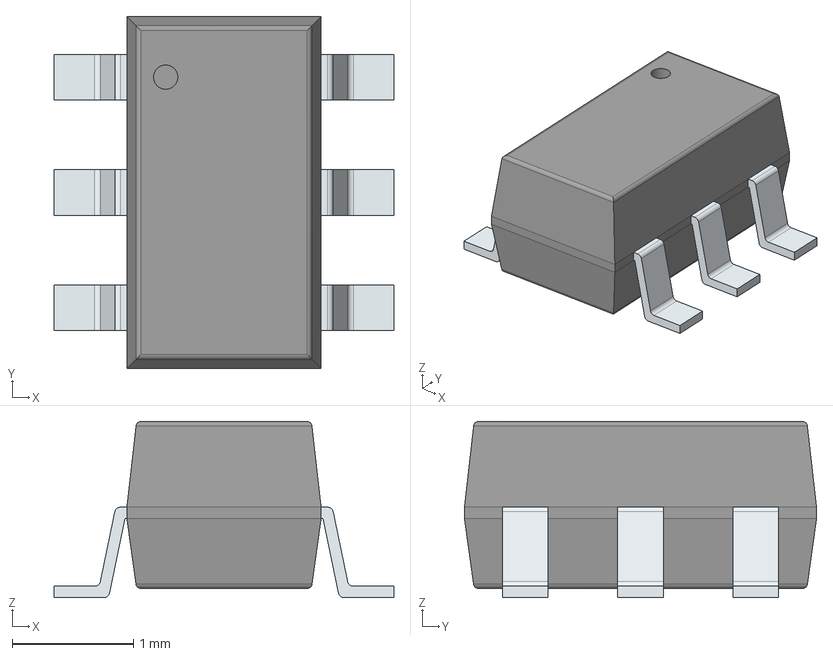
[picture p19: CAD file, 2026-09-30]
hardware/kicad/myProject_models/SN74LVC2G17DBV_buffer_a_b.step
2.80 x 2.90 x 1.45 mm
PinsArrayLR

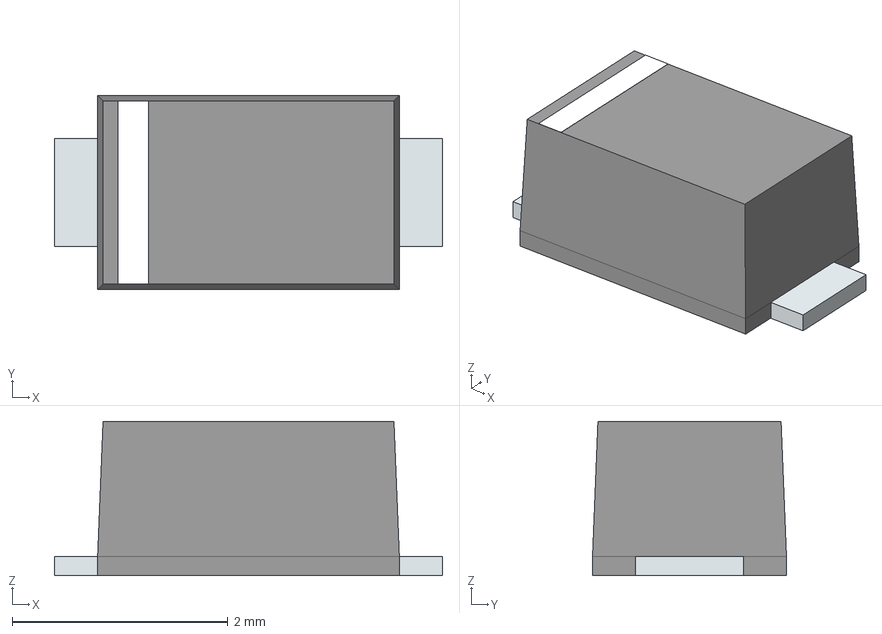
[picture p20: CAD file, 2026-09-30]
hardware/kicad/myProject_models/SS34FAschottky.step
3.60 x 1.80 x 1.43 mm
PinKIdent
PinK
PinA

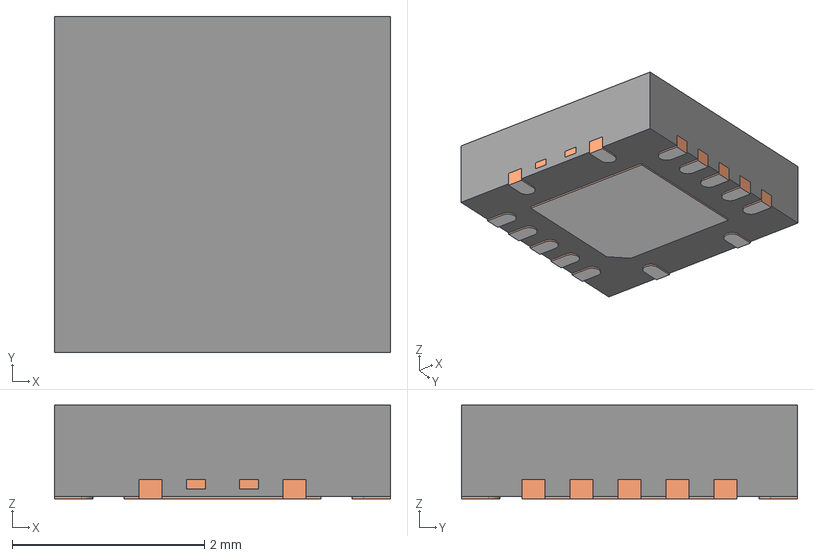
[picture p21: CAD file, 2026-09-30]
hardware/kicad/myProject_models/SN74AHCT125RGYR_buffer_cs_clk.step
3.50 x 3.50 x 0.975 mm
BODY-QFN
FRAME-RWA0014A
PIN1-ID

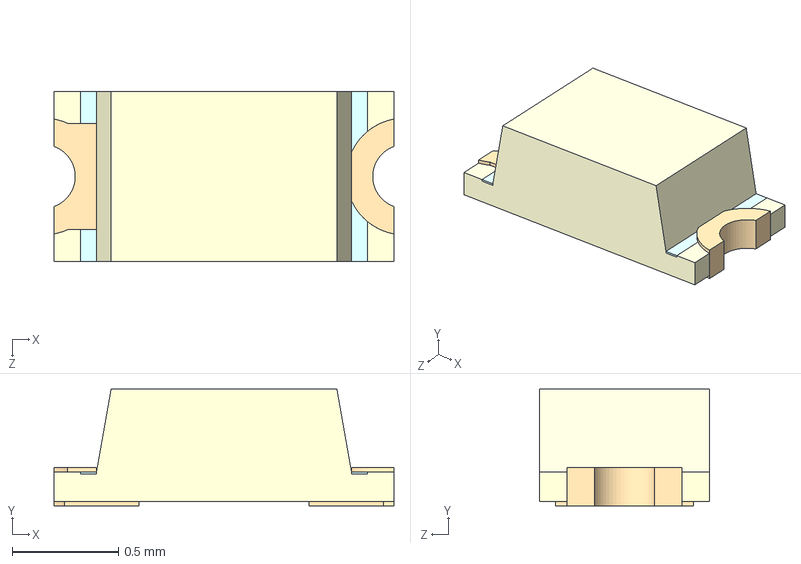
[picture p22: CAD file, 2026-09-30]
hardware/kicad/myProject_models/SML-D12FWT86_gled.step
1.60 x 0.55 x 0.8 mm

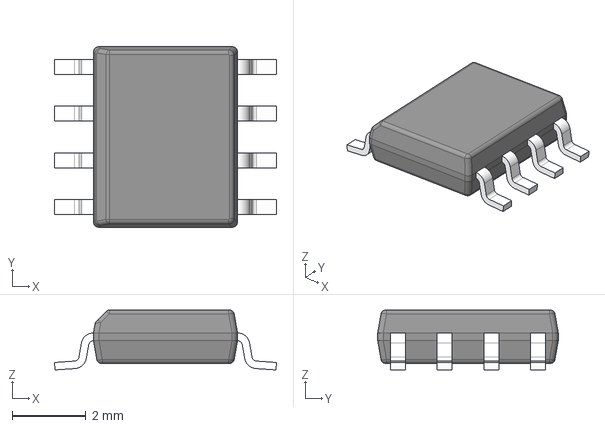
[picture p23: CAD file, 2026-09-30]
hardware/kicad/myProject_models/REF5050AIDR.step
6.02 x 4.90 x 1.63 mm
BODY-SO
LEAD-D0008A x 8

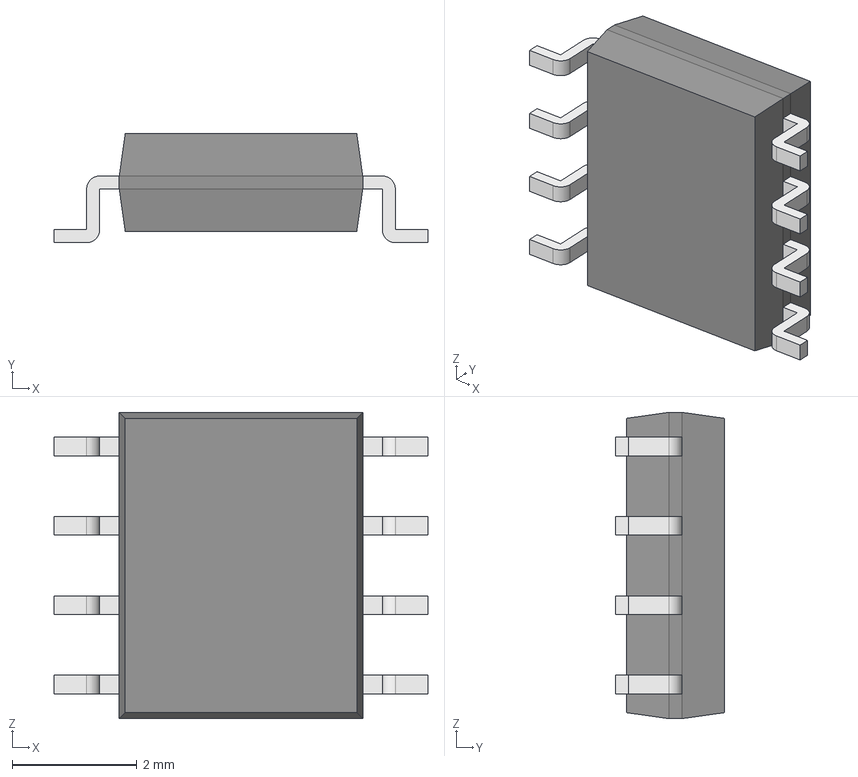
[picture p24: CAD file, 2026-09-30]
hardware/kicad/myProject_models/TPS5410DRbuck.STEP
5.99 x 1.75 x 4.91 mm
Body001 (Mirror #1) x 4
XY-plane x 12
X-axis x 12

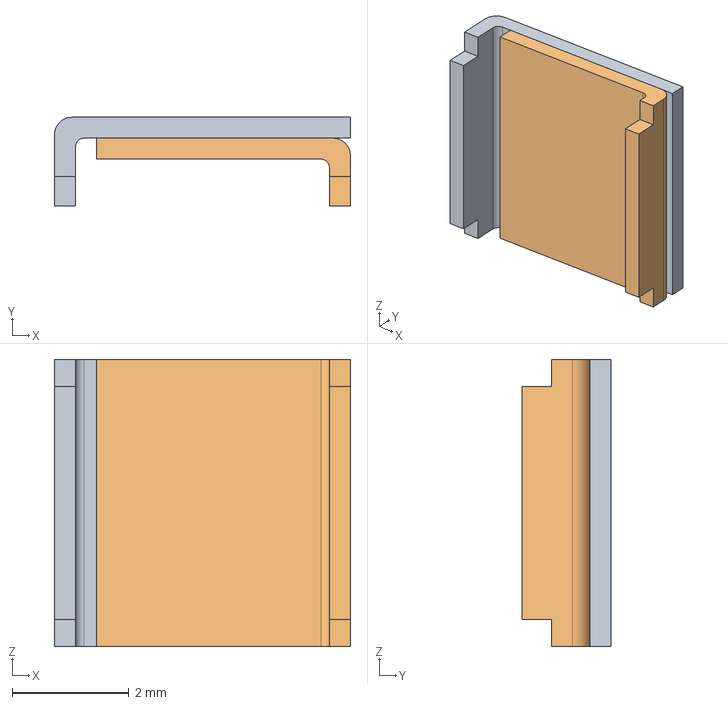
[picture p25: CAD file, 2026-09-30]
hardware/kicad/myProject_models/SMD100F-2018-2_polyfuse.step
5.08 x 1.52 x 4.93 mm

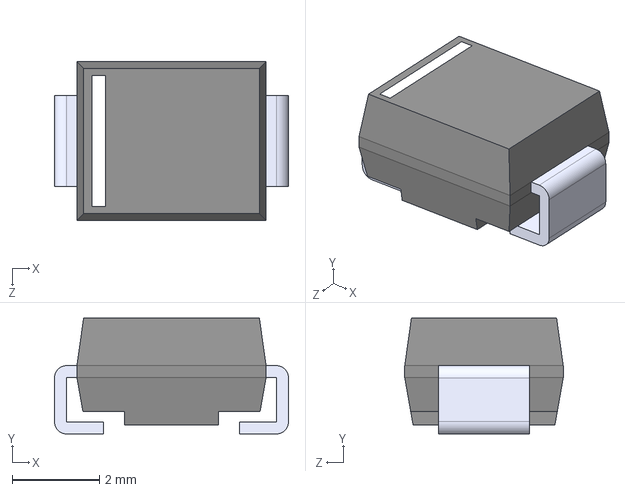
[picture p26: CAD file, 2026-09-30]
hardware/kicad/myProject_models/SMBJ12A_tvs.step
5.35 x 2.65 x 3.62 mm

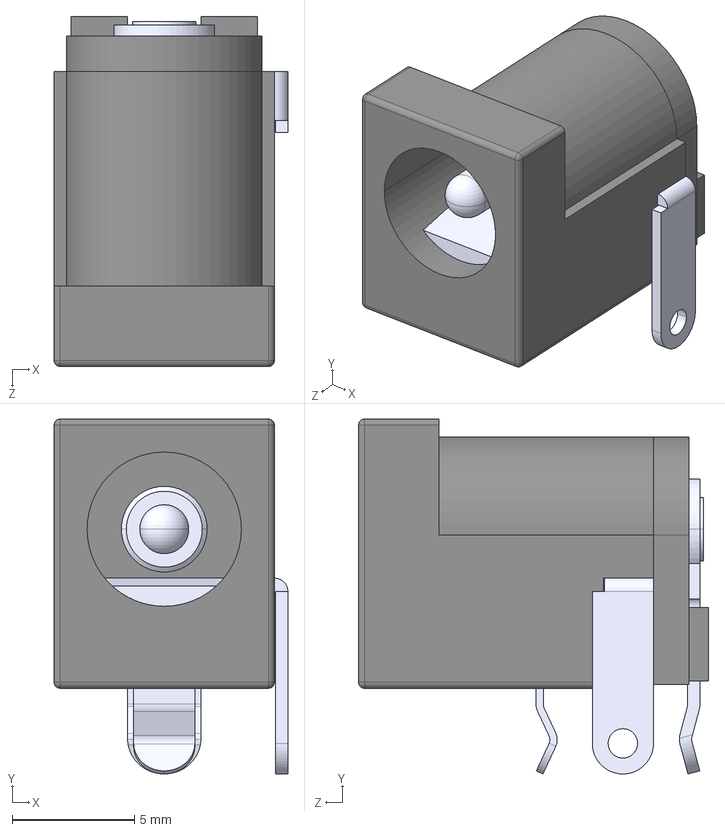
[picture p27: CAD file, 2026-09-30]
hardware/kicad/myProject_models/DCJ200-10-A-K1-Kjack.step
9.55 x 14.5 x 14.3 mm

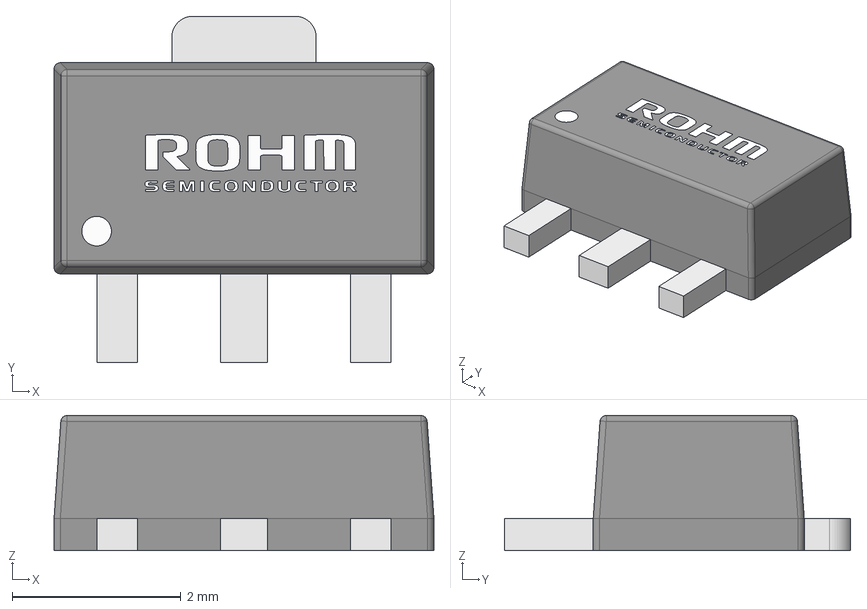
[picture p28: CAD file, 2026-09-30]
hardware/kicad/myProject_models/AP7375-50Y-13_ldo5v.step
4.50 x 4.10 x 1.60 mm
BCX5616TA
Rohm Logo-LAPTOP-NQA1DCQ3

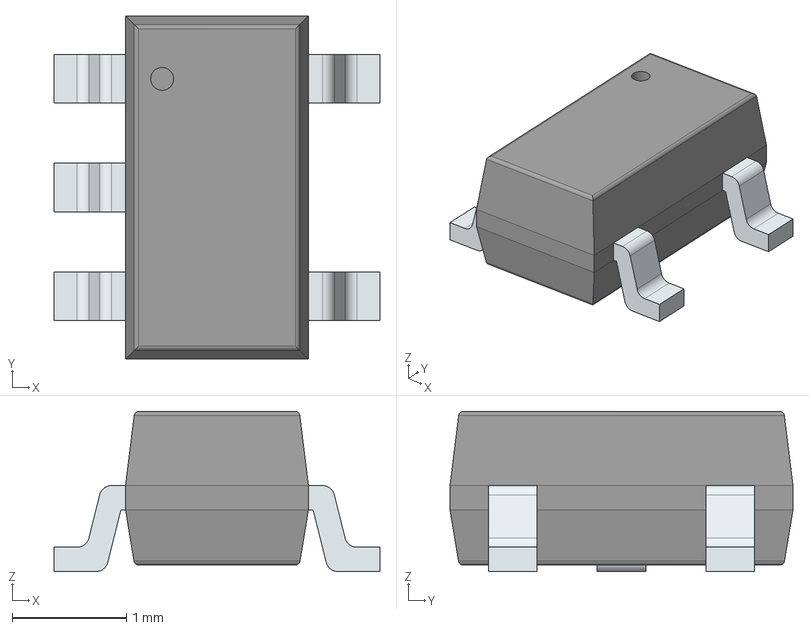
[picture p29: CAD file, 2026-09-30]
hardware/kicad/myProject_models/AP7375-33W5-7_ldo3.3v.step
2.85 x 3.00 x 1.40 mm
PinsArrayL
PinsArrayR

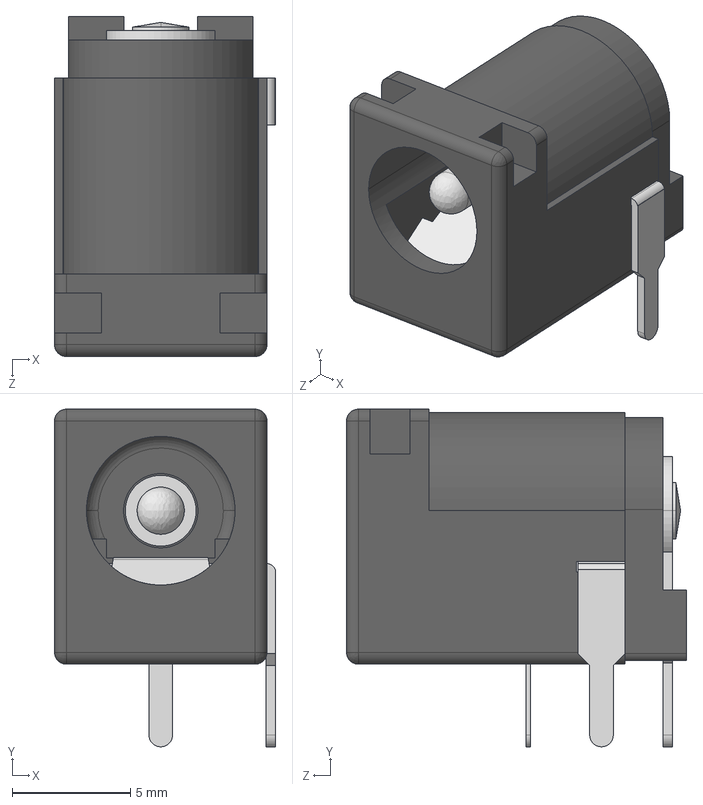
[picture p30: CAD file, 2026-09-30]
hardware/kicad/myProject_models/54-00133jack.step
9.36 x 14.3 x 14.4 mm

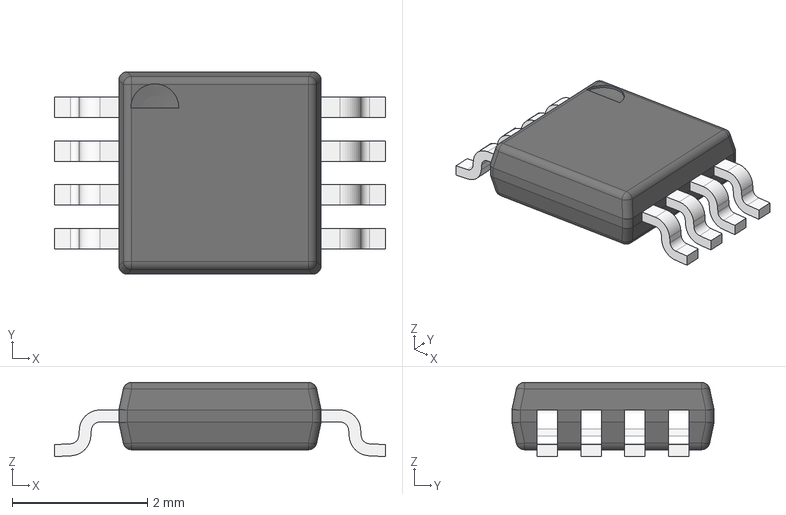
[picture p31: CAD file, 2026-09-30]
hardware/kicad/myProject_models/ADS8320EB_2K5_ADC.step
4.90 x 3.00 x 1.10 mm
BODY_MUA08A
LEAD_MUA08A x 8

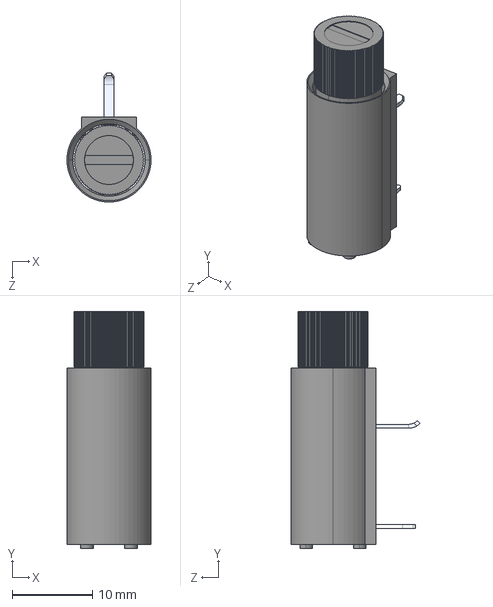
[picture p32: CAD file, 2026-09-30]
hardware/kicad/myProject_models/4525holder.step
10.5 x 29.6 x 16.1 mm

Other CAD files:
hardware/kicad/myProject_models/ACS724LLCTR-05AB-T_acs.step
hardware/kicad/myProject_models/M20-9990446_debug.step
hardware/kicad/myProject_models/B72214P2271K101MOV.step
hardware/kicad/myProject_models/L101011MS02Q_pswitch.step
hardware/kicad/myProject_models/0215001.MXP_fuse.step
hardware/kicad/myProject_models/1730395_AC_LOAD_con.stp
hardware/kicad/myProject_models/69168-112HLF-Odd_Even.STEP
hardware/kicad/myProject_models/744770168_inductor.step

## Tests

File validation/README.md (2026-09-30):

# Laboratory validation data

Raw measurement captures used during the final project validation.

The source captures are preserved rather than overwritten by cleaned or processed versions.

## CSV schema

The GUI recording format contains:

```text
timestamp_utc
frame_sequence
sample_index
sample_time_s
sample_rate_hz
voltage_raw_code
current_raw_code
scaled_voltage_v
scaled_current_a
```

## Voltage data

`voltage/raw/` contains the function-generator tests used to check the voltage measurement chain, including 5 Vpp, 7.5 Vpp and 10 Vpp captures and calibration/zero-input runs.

`voltage/zero_input/` contains additional no-signal recordings.

The laboratory setup did not provide a variable mains AC source or power amplifier, so these results validate the low-voltage response of the implemented chain rather than a full standards-grade mains calibration.

The larger calibration capture is stored losslessly as:

```text
voltage/raw/raw_adc_cali_10pp.csv.gz
```

Decompress it with `gzip -dk` before running scripts that expect a plain CSV.

## Current data

`current/raw/` contains the DC current-calibration captures.

Reference points used during the final test sequence were approximately:

| Repository file | Ammeter reference |
|---|---:|
| `raw_adc_I_zero_A.csv` | ~0 A |
| `raw_adc_0.05A.csv.gz` | 0.051 A |
| `raw_adc_0.10A.csv` | 0.100 A |
| `raw_adc_0.15A.csv` | 0.151 A |
| `raw_adc_0.2A.csv.gz` | 0.200 A |
| `raw_adc_0.25A.csv.gz` | 0.251 A |
| `raw_adc_0.3A.csv` | 0.300 A |
| `raw_adc_20260917_0.35A.csv` | 0.358 A |
| `raw_adc_0.4A.csv` | 0.403 A |
| `raw_adc_0.45A.csv` | 0.459 A |

Testing stopped at the highest point because of resistive-load heating.

The `.gz` files are ordinary gzip-compressed CSV files. Compression is lossless and used only for the captures that were too large for the repository-transfer path used during publication.

Example:

```bash
gzip -dk current/raw/raw_adc_0.25A.csv.gz
```

## Data cleaning rule

The raw files contain occasional acquisition glitches. Keep the original files unchanged.

For statistical summaries/plots, isolated exact ADC codes such as `24576` and `49152` are excluded when they represent acquisition glitches rather than valid measurements. The helper script in `analysis/` implements this conservative filter.

## Quick summary script

For an uncompressed capture:

```bash
python analysis/summarize_adc_csv.py current/raw/raw_adc_0.10A.csv --channel current
```

or:

```bash
python analysis/summarize_adc_csv.py voltage/raw/raw_adc_10pp.csv --channel voltage
```

The script reports sample count, raw-code mean/standard deviation and scaled-value statistics after removing the known isolated glitch codes.

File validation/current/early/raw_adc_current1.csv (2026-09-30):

timestamp_utc | frame_sequence | sample_index | sample_time_s | sample_rate_hz | voltage_raw_code | current_raw_code | scaled_voltage_v | scaled_current_a
2026-09-15T20:31:19.725556+00:00 | 1025 | 0 | 0.000000000 | 10000 | 32768 | 32768 | -0.591000000 | 0.019502000000
2026-09-15T20:31:19.725556+00:00 | 1025 | 1 | 0.000100000 | 10000 | 32768 | 32768 | -0.591000000 | 0.019502000000
2026-09-15T20:31:19.725556+00:00 | 1025 | 2 | 0.000200000 | 10000 | 32768 | 32768 | -0.591000000 | 0.019502000000
2026-09-15T20:31:19.725556+00:00 | 1025 | 3 | 0.000300000 | 10000 | 32768 | 32768 | -0.591000000 | 0.019502000000
2026-09-15T20:31:19.725556+00:00 | 1025 | 4 | 0.000400000 | 10000 | 32817 | 32644 | 0.115000000 | 0.013589000000
2026-09-15T20:31:19.725556+00:00 | 1025 | 5 | 0.000500000 | 10000 | 32811 | 32695 | 0.028000000 | 0.016021000000
2026-09-15T20:31:19.725556+00:00 | 1025 | 6 | 0.000600000 | 10000 | 32768 | 32768 | -0.591000000 | 0.019502000000
2026-09-15T20:31:19.725556+00:00 | 1025 | 7 | 0.000700000 | 10000 | 32768 | 32768 | -0.591000000 | 0.019502000000
2026-09-15T20:31:19.725556+00:00 | 1025 | 8 | 0.000800000 | 10000 | 32768 | 32768 | -0.591000000 | 0.019502000000
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

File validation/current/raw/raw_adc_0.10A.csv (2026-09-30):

timestamp_utc | frame_sequence | sample_index | sample_time_s | sample_rate_hz | voltage_raw_code | current_raw_code | scaled_voltage_v | scaled_current_a
2026-09-17T15:15:10.926610+00:00 | 413 | 0 | 0.000000000 | 10000 | 32889 | 34658 | 1.153000000 | 0.109625000000
2026-09-17T15:15:10.926610+00:00 | 413 | 1 | 0.000100000 | 10000 | 32895 | 34483 | 1.240000000 | 0.101280000000
2026-09-17T15:15:10.926610+00:00 | 413 | 2 | 0.000200000 | 10000 | 32891 | 34529 | 1.182000000 | 0.103474000000
2026-09-17T15:15:10.926610+00:00 | 413 | 3 | 0.000300000 | 10000 | 32893 | 34333 | 1.211000000 | 0.094128000000
2026-09-17T15:15:10.926610+00:00 | 413 | 4 | 0.000400000 | 10000 | 32891 | 34389 | 1.182000000 | 0.096798000000
2026-09-17T15:15:10.926610+00:00 | 413 | 5 | 0.000500000 | 10000 | 32895 | 34389 | 1.240000000 | 0.096798000000
2026-09-17T15:15:10.926610+00:00 | 413 | 6 | 0.000600000 | 10000 | 32895 | 34361 | 1.240000000 | 0.095463000000
2026-09-17T15:15:10.926610+00:00 | 413 | 7 | 0.000700000 | 10000 | 32891 | 34406 | 1.182000000 | 0.097609000000
2026-09-17T15:15:10.926610+00:00 | 413 | 8 | 0.000800000 | 10000 | 32891 | 34403 | 1.182000000 | 0.097466000000
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

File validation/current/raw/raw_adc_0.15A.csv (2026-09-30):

timestamp_utc | frame_sequence | sample_index | sample_time_s | sample_rate_hz | voltage_raw_code | current_raw_code | scaled_voltage_v | scaled_current_a
2026-09-17T15:19:16.901618+00:00 | 530 | 0 | 0.000000000 | 10000 | 32933 | 35511 | 1.788000000 | 0.150299000000
2026-09-17T15:19:16.901618+00:00 | 530 | 1 | 0.000100000 | 10000 | 32922 | 35569 | 1.629000000 | 0.153065000000
2026-09-17T15:19:16.901618+00:00 | 530 | 2 | 0.000200000 | 10000 | 32940 | 35591 | 1.889000000 | 0.154114000000
2026-09-17T15:19:16.901618+00:00 | 530 | 3 | 0.000300000 | 10000 | 32921 | 35615 | 1.615000000 | 0.155259000000
2026-09-17T15:19:16.901618+00:00 | 530 | 4 | 0.000400000 | 10000 | 32934 | 35629 | 1.802000000 | 0.155926000000
2026-09-17T15:19:16.901618+00:00 | 530 | 5 | 0.000500000 | 10000 | 32931 | 35695 | 1.759000000 | 0.159073000000
2026-09-17T15:19:16.901618+00:00 | 530 | 6 | 0.000600000 | 10000 | 32921 | 35369 | 1.615000000 | 0.143528000000
2026-09-17T15:19:16.901618+00:00 | 530 | 7 | 0.000700000 | 10000 | 32933 | 35263 | 1.788000000 | 0.138474000000
2026-09-17T15:19:16.901618+00:00 | 530 | 8 | 0.000800000 | 10000 | 32917 | 35353 | 1.557000000 | 0.142765000000
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

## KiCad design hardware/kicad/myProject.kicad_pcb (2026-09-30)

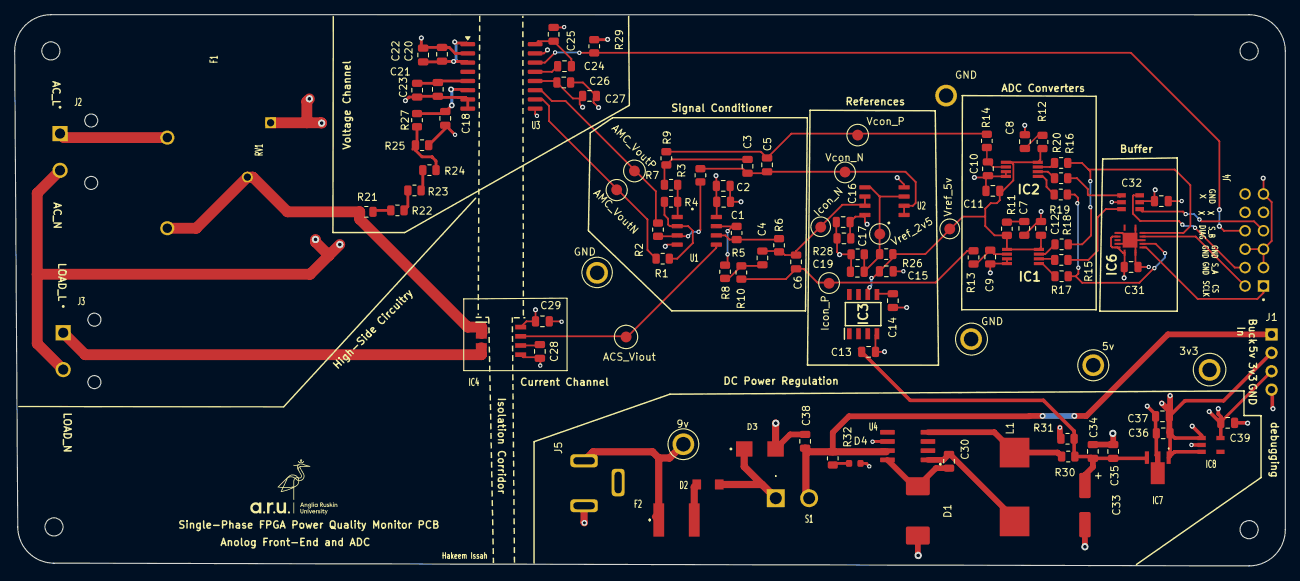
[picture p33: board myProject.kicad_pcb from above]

Board: 4 copper layers, 175.3 x 76.1 mm, 112 parts (0 on the bottom side), 62 nets.

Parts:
3v3: +3.3V; TestPoint_Plated_Hole_D2.0mm
5v: +5V; TestPoint_Plated_Hole_D2.0mm
9v: +9V_IN; TestPoint_Plated_Hole_D2.0mm
ACS_Viout: ACS_Viout; TestPoint_Pad_D1.5mm
AMC_VoutN: AMC_VoutN; TestPoint_Pad_D1.5mm
AMC_VoutP: AMC_VoutP; TestPoint_Pad_D1.5mm
C1, C16, C21, C24, C25, C29, C31, C32, C35, C37: 100n; C_0805_2012Metric
C2, C13, C17: 4u7; C_0805_2012Metric
C3, C4, C5, C6: 33n; C_0805_2012Metric
C7, C8, C15, C39: 10u; C_0805_2012Metric
C9, C10, C18, C22, C23, C27: 1n; C_0805_2012Metric
C11, C12, C14, C19, C20, C26, C34, C36: 1u; C_0805_2012Metric
C28: 4n7; C_0805_2012Metric
C30: 10n; C_0805_2012Metric
C33: 47u; CP_Elec_6.3x5.8_custom
C38: 4.7uF; C_0805_2012Metric
D1: B340; D_SMC_custom
D2: SS34FA; SODFL3618X143Nschottky
D3: SMBJ12A; DIOM4336X265N_tvs_custom
D4: SML-D12FWT86; LED_0603_1608Metric_custom
F1: 4525holder & 0215001 fuse_catridge(installed); FUSE_4525holder
F2: SMD100F-2018-2; SMD030F20182_polyfuse
GND: GND; TestPoint_Plated_Hole_D2.0mm
GND#2, GND#3: GND; TestPoint_Plated_Hole_D2.0mm
IC1, IC2: ADS8320EB_2K5; SOP65P490X110-8N_ADC_custom
IC3: REF5050AIDR; SOIC127P600X175-8N_REF
IC4: ACS724LLCTR-05AB-T; SOIC127P600X175-8N_acs
IC5: SN74LVC2G17DBVR; SOT95P280X145-6N_buffer_a_b_custom
IC6: SN74AHCT125RGYR; RGY-_S-PVQFN-N14_cs_clk_custom
IC7: AP7375-50Y-13; AZ7042RTRG1_ldo5v
IC8: AP7375-33W5-7; SOT95P285X140-5N_ldo3.3v_custom
Icon_N: Icon_N; TestPoint_Pad_D1.5mm
Icon_P: Icon_P; TestPoint_Pad_D1.5mm
J1: Conn_01x04(debugging); PinHeader_1x04_P2.54mm_Vertical
J2: 1730395(ac_input); PHOENIX_1730395_ac_load_con
J3: 1730395(load); PHOENIX_1730395_ac_load_con
J4: 69168-112HLF; AMPHENOL_69168-112HLF_Odd_Even
J5: XDJK-0051-025_barrel; DC-470-2.1GP_C194407_barrel_custom
L1: 744770168; Inductor_new_YJYCOIN_YSPI1040T_custom
R1, R2, R3, R4, R26, R28, R30: 10k; R_0805_2012Metric
R5: 30K; R_0805_2012Metric
R6: 10K; R_0805_2012Metric
R7, R8, R9, R10, R27: 1k; R_0805_2012Metric
R11, R12: 0.22; R_0805_2012Metric
R13, R14: 100; R_0805_2012Metric
R15, R16, R17, R18, R19, R20: 47; R_0805_2012Metric
R21, R22, R23, R24: 499k; R_0805_2012Metric
R25: 4k99; R_0805_2012Metric
R29: 47k; R_0805_2012Metric
R31: 2k55; R_0805_2012Metric
R32: 2k2; R_0805_2012Metric
RV1: B72214P2271K101; B72214P2271K101MOVV
S1: L101011MS02Q; L101011MS02Q_pswitch
U1, U2: OPA2188AID; SOIC127P599X175-8Nopamp
U3: AMC3330; SOIC-16W_7.5x10.3mm_P1.27mm_custom
U4: TPS5410DR; SOIC127P599X175-8Nbuck
Vcon_N: Vcon_N; TestPoint_Pad_D1.5mm
Vcon_P: Vcon_P; TestPoint_Pad_D1.5mm
Vref_2v5: Vref_2v5; TestPoint_Pad_D1.5mm_custom
Vref_5v: Vref_5v; TestPoint_Pad_D1.5mm_custom

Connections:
+3.3V: 3v3.1, C32.1, C39.1, IC5.5 (VCC), IC8.5 (VOUT), J1.3, R29.1
+5V: 5v.1, C1.1, C2.1, C16.1, C17.1, C26.1, C27.1, C29.1, C31.1, C36.1, C37.1, IC4.8 (VCC), IC6.10 (3~OE), IC6.13 (4~OE), IC6.14 (VCC), IC7.1 (VOUT), IC8.1 (VIN), IC8.3 (EN), J1.2, U1.8 (V+), U2.8 (V+), U3.12 (VDD)
/+6V: C13.1, C33.1, C34.1, C35.1, IC7.3 (VIN), R30.2, R31.2
/+9V_IN: 9v.1, F2.1, J5.1
/ACS_Viout: ACS_Viout.1, IC4.7 (VIOUT), U1.5 (+INB)
/AC_L: F1.1, J2.1
/AC_N: C18.2, C20.2, C21.2, C22.2, C23.2, J2.2, J3.2, R25.1, RV1.1, U3.2 (DCDC_HGND), U3.7 (INN), U3.8 (HGND)
/AC_Path/FUSED_AC_L: F1.2, IC4.1 (IP+_1), IC4.2 (IP+_2), R21.1, RV1.2
/AC_Path/V_DIV: C18.1, R27.2, U3.6 (INP)
/AMC_VoutN: AMC_VoutN.1, R1.1, U3.10 (OUTN)
/AMC_VoutP: AMC_VoutP.1, R2.1, U3.11 (OUTP)
/Buck_Vin: C38.1, J1.1, R32.1, S1.2, U4.7 (VIN)
/CS: IC6.3 (1Y), R17.2, R19.2
/DIAG: J4.B4, R29.2, U3.14 (DIAG)
/DOUT_A: IC5.1 (1A), R16.2
/DOUT_B: IC5.3 (2A), R15.2
/FPGA_CS: IC6.2 (1A), J4.A1
/FPGA_SCLK: IC6.5 (2A), J4.B1
/Icon_N: C4.1, C6.1, Icon_N.1, R6.2, U2.6 (-INB), U2.7 (OUTB)
/Icon_P: C6.2, Icon_P.1, R10.2, R13.1
/LOAD_L: IC4.3 (IP-_1), IC4.4 (IP-_2), J3.1
/SCLK: IC6.6 (2Y), R18.2, R20.2
/SDO_A: IC5.6 (1Y), J4.B2
/SDO_B: IC5.4 (2Y), J4.A4
/Vcon_N: C3.2, C5.2, R3.2, U2.1 (OUTA), U2.2 (-INA), Vcon_N.1
/Vcon_P: C5.1, R9.2, R14.1, Vcon_P.1
/Vref_2v5: C19.1, R26.2, R28.1, U2.3 (+INA), U2.5 (+INB), Vref_2v5.1
/Vref_5v: C11.1, C12.1, C15.1, IC1.1 (VREF), IC1.8 (+VCC), IC2.1 (VREF), IC2.8 (+VCC), IC3.6 (VOUT), R11.1, R12.1, R26.1, Vref_5v.1
GND: C1.2, C2.2, C7.2, C8.2, C9.2, C10.2, C11.2, C12.2, C13.2, C14.2, C15.2, C16.2, C17.2, C19.2, C25.2, C26.2, C27.2, C28.2, C29.2, C31.2, C32.2, C33.2, C34.2, C35.2, C36.2, C37.2, C38.2, C39.2, D1.2 (A), D3.A, D4.2 (C), GND.1, GND#2.1, GND#3.1, IC1.3 (-IN), IC1.4 (GND), IC2.3 (-IN), IC2.4 (GND), IC3.4 (GND), IC4.5 (GND), IC5.2 (GND), IC6.1 (1~OE), IC6.4 (2~OE), IC6.7 (GND), IC6.9 (3A), IC6.12 (4A), IC6.15 (THERMAL_PAD), IC7.2 (GND_1), IC8.2 (GND), J1.4, J4.A2, J4.A3, J4.A6, J4.B3, J5.2, R28.2, R31.1, U1.4 (V-), U2.4 (V-), U3.9 (GND), U3.15 (DCDC_GND), U4.6 (GND)
unnamed: C3.1, R7.2, R9.1
unnamed: C4.2, R8.2, R10.1
unnamed: C7.1, R11.2
unnamed: C8.1, R12.2
unnamed: C30.1, D1.1 (K), U4.8 (PH)
unnamed: D2.2 (A), F2.2
unnamed: D2.1 (K), D3.C, S1.1
unnamed: D4.1 (A), R32.2
unnamed: C9.1, IC1.2 (+IN), R13.2
unnamed: IC1.7 (DCLOCK), R18.1
unnamed: IC1.6 (DOUT), R15.1
unnamed: IC1.5 (~CS/SHDN), R17.1
unnamed: C10.1, IC2.2 (+IN), R14.2
unnamed: IC2.7 (DCLOCK), R20.1
unnamed: IC2.6 (DOUT), R16.1
unnamed: IC2.5 (~CS/SHDN), R19.1
unnamed: C14.1, IC3.5 (TRIM/NR)
unnamed: C28.1, IC4.6 (FILTER)
unnamed: R21.2, R22.1
unnamed: R22.2, R23.1
unnamed: R23.2, R24.1
unnamed: R24.2, R25.2, R27.1
unnamed: R2.2, R3.1, U1.3 (+INA)
unnamed: R1.2, R4.1, U1.2 (-INA)
unnamed: R5.1, R6.1, U1.6 (-INB)
unnamed: R4.2, R7.1, U1.1 (OUTA)
unnamed: R5.2, R8.1, U1.7 (OUTB)
unnamed: C24.2, C25.1, U3.16 (DCDC_IN)
unnamed: C20.1, C22.1, U3.1 (DCDC_OUT), U3.3 (HLDO_IN)
unnamed: C21.1, C23.1, U3.5 (HLDO_OUT)
unnamed: C24.1, U3.13 (LDO_OUT)
unnamed: C30.2, L1.2, U4.1 (BOOT)
unnamed: L1.1, R30.1, U4.4 (VSENSE)

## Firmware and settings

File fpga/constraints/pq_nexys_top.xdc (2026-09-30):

######################################################################
# Nexys A7-100T constraints
######################################################################


######################################################################
# 100 MHz clock
######################################################################

set_property -dict { PACKAGE_PIN E3 IOSTANDARD LVCMOS33 } \
    [get_ports { CLK100MHZ }]

create_clock -add \
    -name sys_clk_pin \
    -period 10.000 \
    -waveform {0.000 5.000} \
    [get_ports { CLK100MHZ }]


######################################################################
# Reset pushbutton: BTNC
######################################################################

set_property -dict { PACKAGE_PIN N17 IOSTANDARD LVCMOS33 } \
    [get_ports { RESET }]


######################################################################
# PMOD JA - ADC interface
######################################################################

# JA1 : FPGA -> PCB ADC chip select
set_property -dict { PACKAGE_PIN C17 IOSTANDARD LVCMOS33 } \
    [get_ports { ADC_CS_N }]

# JA2 : FPGA -> PCB ADC serial clock
set_property -dict { PACKAGE_PIN D18 IOSTANDARD LVCMOS33 } \
    [get_ports { ADC_DCLOCK }]

# JA3 : Voltage ADC data -> FPGA
set_property -dict { PACKAGE_PIN E18 IOSTANDARD LVCMOS33 } \
    [get_ports { ADC_DOUT_V }]

# JA4 : Current ADC data -> FPGA
set_property -dict { PACKAGE_PIN G17 IOSTANDARD LVCMOS33 } \
    [get_ports { ADC_DOUT_I }]


######################################################################
# Onboard USB-UART
# FPGA -> PC
######################################################################

set_property -dict { PACKAGE_PIN D4 IOSTANDARD LVCMOS33 } \
    [get_ports { UART_TX }]

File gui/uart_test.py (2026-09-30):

import serial
import time

PORT = "COM3"       # CHANGE THIS
BAUD = 115200

ser = serial.Serial(PORT, BAUD, timeout=1)

print(f"Opened {PORT} at {BAUD} baud")
print("Waiting for FPGA data...\n")

while True:
    data = ser.read(100)

    if data:
        print(f"{len(data)} bytes:", data.hex(" "))
    else:
        print("NO DATA")

    time.sleep(0.2)

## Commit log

2026-09-30 Initialize FPGA power quality monitor repository
2026-09-30 Add gui/uart_test.py
2026-09-30 Add gui/uart_test1.py
2026-09-30 Add fpga/src/sample_preprocess.vhd
2026-09-30 Add fpga/src/uart_tx.vhd
2026-09-30 Add acquisition and ADC processing sources
2026-09-30 Add frequency, harmonic and power measurement sources
2026-09-30 Add UART and ADC simulation testbenches
2026-09-30 Add harmonic, THD and power simulations
2026-09-30 Add frame, scaling and THD simulations
2026-09-30 Add legacy development modules for traceability
2026-09-30 Add GUI application and UART utility scripts
2026-09-30 Add Vivado image and primary KiCad project files
    [ac_path.kicad_sch, myProject.kicad_pcb]
2026-09-30 Add KiCad schematic and custom footprints
    [myProject.kicad_sch]
2026-09-30 Add custom KiCad footprints
2026-09-30 Add additional custom KiCad footprints
2026-09-30 Add connector and passive-component footprints
2026-09-30 Add interface and connector footprints
2026-09-30 Add resistor and package footprints
2026-09-30 Add op-amp, ADC and regulator footprints
2026-09-30 Add ADC, buffer and LDO footprints
2026-09-30 Add regulator, jack and test-point footprints
2026-09-30 Complete custom footprint library and add fuse model
    [0215001.MXP_fuse.step]
2026-09-30 Add AC load connector 3D model
    [1730395_AC_LOAD_con.stp]
2026-09-30 Add fuse-holder 3D model
    [4525holder.step]
2026-09-30 Add ADC, connector and sensing 3D models
    [54-00133jack.step, 69168-112HLF-Odd_Even.STEP, 744770168_inductor.step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]
2026-09-30 Add regulator, protection and switch 3D models
    [AP7375-33W5-7_ldo3.3v.step, AP7375-50Y-13_ldo5v.step, B72214P2271K101MOV.step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]
2026-09-30 Add op-amp, reference and protection 3D models
    [M20-9990446_debug.step, OPA2188AIDopamp.step, REF5050AIDR.step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]
2026-09-30 Complete PCB 3D model library
    [SML-D12FWT86_gled.step, SN74AHCT125RGYR_buffer_cs_clk.step, SN74LVC2G17DBV_buffer_a_b.step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]
2026-09-30 Add custom KiCad symbols
2026-09-30 Add sensing, ADC and regulator KiCad symbols
2026-09-30 Add power and analogue KiCad symbols
2026-09-30 Add protection, LED and digital-buffer KiCad symbols
2026-09-30 Complete KiCad symbol library and power schematic
    [power.kicad_sch]
2026-09-30 Add PCB BOM and initial Gerber outputs
    [MyBOM_JLCPCB.xlsx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]
2026-09-30 Add front and inner PCB Gerbers
    [myProject-F_Cu.gbr, myProject-F_Mask.gbr, myProject-F_Paste.gbr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]
2026-09-30 Add remaining PCB Gerbers and drill files
    [myProject-In2_Cu.gbr, myProject-NPTH-drl_map.gbr, myProject-NPTH.drl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]
2026-09-30 Complete manufacturing outputs and add early current capture
    [raw_adc_current1.csv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]
2026-09-30 Add 0.10 A current validation dataset
    [raw_adc_0.10A.csv]
2026-09-30 Add 0.15 A current validation dataset
    [raw_adc_0.15A.csv]
2026-09-30 Add 0.30 A and 0.45 A current validation datasets
    [raw_adc_0.3A.csv, raw_adc_0.45A.csv]
2026-09-30 Add 0.40 A current validation dataset
    [raw_adc_0.4A.csv]
2026-09-30 Add 0.358 A current validation dataset
    [raw_adc_20260917_0.35A.csv]
2026-09-30 Add zero-current validation dataset
    [raw_adc_I_zero_A.csv]
2026-09-30 Add 10 Vpp and 5 Vpp voltage validation datasets
    [raw_adc_10pp.csv, raw_adc_5pp.csv]
2026-09-30 Add 7.5 Vpp and zero-input voltage calibration datasets
    [raw_adc_7.5pp.csv, raw_adc_cali_zeroinput.csv]
2026-09-30 Add additional voltage calibration captures
    [raw_adc_new_zeroinput.csv, raw_adc_newer_10pp.csv]
2026-09-30 Add zero-input voltage captures
    [raw_adc_20260914_213307.csv, raw_adc_new.csv]
2026-09-30 Complete zero-input voltage validation captures
    [raw_adc_newer.csv, raw_adc_newerrrr.csv]
2026-09-30 Add compressed oversized current validation datasets
